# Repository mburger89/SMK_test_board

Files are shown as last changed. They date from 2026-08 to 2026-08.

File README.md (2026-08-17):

# SMK Test Board

A 3×3 macropad built around the Seeed XIAO ESP32-C6, with a rotary encoder and
per-key RGB. It exists to validate the [SMK](https://github.com/mburger89/SMK)
keyboard firmware and the
[SMK Configurator](https://github.com/mburger89/smk_configurator) editor on real
hardware — small enough to be cheap, complete enough to exercise every subsystem
the full keyboard depends on.

Two of those subsystems have never run against physical hardware at all: the RMT
LED driver and `BatteryMonitor`. This board is where they get their first test.

**The schematic and PCB are generated by a Python script, not drawn by hand.**
`generate_test_board.py` is the source of truth; the files under
`smk_test_board/` are its output and should never be hand-edited.

## Status

Design complete, reviewed, and DRC-clean. **Not yet fabricated.**

Before ordering, `docs/fabrication.md` opens with a STOP gate: two footprints —
`XIAO_ESP32C6_HEADERS` and `EC11_VERTICAL` — were drawn from datasheet
dimensions and have never been checked against real parts. Print the board 1:1
and hold the physical XIAO and EC11 against the paper first. A wrong
castellation pitch or encoder pin spacing is not reworkable; it means a second
fab run.

## What's on it

| | |
|---|---|
| MCU | Seeed XIAO ESP32-C6 on 1×7 female headers |
| Matrix | 3×3, 19.05 mm pitch, Gateron KS-33 hot-swap sockets, SOD-123 diodes |
| Encoder | EC11 vertical; its push-switch **is** matrix position row 0, col 2 |
| RGB | 9 × SK6812MINI-E, reverse-mount, one per key, behind an SN74AHCT1G125 level shifter |
| Power | USB-C on the XIAO, or a single-cell Li-ion via JST **SH** (1.0 mm) with flying leads to the module's underside BAT pads |
| Battery sense | External 1:2 divider (2 × 200 kΩ) into GPIO 0 |
| Board | 2-layer, 76.0 × 113.16 mm, 1.6 mm |

The nine LEDs are reverse-mount and shine *through* milled windows in the board
into each switch's north opening. Those windows are internal `Edge.Cuts`
cutouts, not decoration — a fab house that ignores them produces a board whose
LEDs do nothing.

## Pin map

This is a contract shared by four repositories, and all four must agree:

| Signal | GPIO |
|---|---|
| ROW0–2 | 1, 2, 21 |
| COL0–2 | 22, 23, 16 (`colsAreDriven = 1`) |
| LED data | 20 |
| VBAT sense | 0 (ADC1_CH0) |
| Encoder A/B | 17, 19 |

The four places it appears: `generate_test_board.py`'s `PIN` map, the firmware's
`Main.swift`/`Kconfig.projbuild`, the configurator's
`KeyboardDesign.smkTestBoard`, and this repo's `keymap.json`.

**Encoder rotation is not implemented.** GPIO 17/19 are wired and idle — nothing
decodes quadrature yet. That gets its own design once this board physically
exists. The encoder's *push* works, because it is an ordinary matrix position.

The LED chain is wired **serpentine** (even rows left-to-right, odd rows
right-to-left) to match `ledChainIndex()` in the firmware's
`SMKCore/LEDChainMapping.swift`. This is easy to get wrong and invisible when you
do: on a 3×3, raster and serpentine order agree on rows 0 and 2 and differ only
on row 1. `test_led_chain_order_matches_firmwares_serpentine_mapping` checks all
nine positions for exactly that reason.

## Layout

```
generate_test_board.py     the generator — schematic, PCB, placement, netlist
export_fab.py              gerbers, drill files, and the fab zip
test_test_board.py         netlist, placement, and cross-repo contract tests
test_footprints.py         footprint geometry tests
keymap.json                reference keymap (mo:1 on the encoder press)
smk_test_board/            generated KiCad project — do not hand-edit
smk_test_board.pretty/     local footprint library
docs/fabrication.md        BOM, order spec, DRC triage, pre-order gate
docs/bring-up.md           11-step procedure for a delivered board
docs/superpowers/          design spec and implementation plan
```

## Working on it

```bash
python3 -m venv venv && venv/bin/pip install pytest
venv/bin/python -m pytest          # 23 tests
python3 generate_test_board.py     # regenerate the KiCad project
python3 export_fab.py              # gerbers + drill + zip into gerbers/
```

Regeneration is byte-reproducible, UUIDs included — so after any change to the
generator, `git diff` on `smk_test_board/` shows exactly what moved
electrically. If you expected a documentation-only change and the `.kicad_pcb`
moved, that is a real finding, not noise.

Fabrication output lands in `gerbers/` and is gitignored. Generate it fresh at
order time rather than trusting a checked-in copy.

## Bringing one up

`docs/bring-up.md` is an ordered checklist with a blank result field per step.
The order matters: continuity checks happen **before** the XIAO is ever seated,
and the battery flying leads get soldered before anything is powered from a
cell.

Two things reliably waste an afternoon if you don't know them, and both are
called out in that document:

- The firmware's board selection defaults to the *other* board. Flash without
  changing it and you get the wrong pin map, and every matrix test fails
  confusingly.
- Two-Mac bonding needs `CONFIG_BT_NIMBLE_MAX_BONDS=4`. With the default of 1,
  the second Mac evicts the first and the test cannot pass.

## Known and accepted

- The board ships **ratsnest-only** — no copper routing. `unconnected_items` in
  DRC is expected and is not something to "fix."
- `min_copper_edge_clearance` is relaxed to 0.2 mm in the project file, because
  the SK6812 pads sit ~0.233–0.247 mm from their own light windows. That is a
  **relaxed rule, not a passing check.** The basis for proceeding is precedent:
  the sibling `smk_kbd_rp2040` board shipped 59 instances of this exact
  footprint at the same clearance.
- RGB3 will be visibly dimmer than the rest — the EC11's body covers roughly the
  southern half of its light window. Expected, not a fault.
- Li-ion cells are commonly sold with a JST-**PH** (2.0 mm) pigtail, which will
  not mate with this board's **SH** (1.0 mm) connector. Source an SH cell, an
  adapter, or re-terminate.

## Related

- [SMK](https://github.com/mburger89/SMK) — the firmware. Board config lives
  behind `CONFIG_SMK_BOARD_TEST_BOARD`.
- [SMK Configurator](https://github.com/mburger89/smk_configurator) — the
  keymap editor. `KeyboardDesign.smkTestBoard` describes this board's layout,
  and the DEV pane uploads `keymap.json` to it over BLE.

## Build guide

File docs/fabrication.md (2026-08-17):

# Fabrication — SMK Test Board (rev A)

Bring-up board for SMK's matrix, RMT LED driver, and `BatteryMonitor` on the
ESP32-C6 (Seeed XIAO ESP32-C6). 3x3 key matrix + EC11 rotary encoder, 9x
SK6812MINI-E per-key RGB. See
`docs/superpowers/specs/2026-08-16-smk-test-board-design.md` for the full
design.

## STOP — pre-order gate

**Do not order this board before printing `smk_test_board/smk_test_board.kicad_pcb`
at 1:1 scale and physically checking two footprints against real parts:**

- `XIAO_ESP32C6_HEADERS` — the Seeed XIAO ESP32-C6's 2x7 castellated/header
  footprint.
- `EC11_VERTICAL` — the rotary encoder's footprint.

Both were hand-drawn from datasheet dimensions in Tasks 3 and 4 of this
project and **have never been checked against a physical part.** No other
footprint in this design is new — the switch, diode, LED, passive, and JST
footprints all come from the proven `~/esp/SMK_macro_pad` sibling generator.
These two are the entire risk surface for "board arrives and a part doesn't
fit." A wrong castellation pitch or encoder pin spacing is not reworkable;
it means a second fab run. Print, hold the real XIAO and EC11 against the
paper, and only then run `export_fab.py` for real and place the order.

(`BAT_WIRE_PADS`, added later for the battery flying leads, is also new to
this project, but it is two 1.0 mm-drill through-hole pads on a 5.08 mm
pitch with nothing to mate against — there is no part to check it against
and no way for it to not fit. It does not join the gate.)

This check was **not performed** as part of this task — it requires a
printer and the physical parts, both outside an agent's reach. It is
recorded here as a hard gate for whoever places the order.

## Order specification

| | |
|---|---|
| Fab house | JLCPCB |
| Service | **Bare PCB only — no PCBA/assembly.** See reasoning below. |
| Layers | 2 |
| Dimensions | 76.0 x 113.16 mm |
| Thickness | 1.6 mm |
| Copper weight | 1 oz (JLCPCB default; board has no controlled-impedance or high-current nets that need more) |
| Surface finish | HASL (lead-free) |
| Soldermask / silkscreen | JLCPCB defaults (green / white) — cosmetic only, not specified by the design |
| Min hole / min trace-space | 21 plated holes (all 1.0 mm) and 30 unplated (2.4/3.0/3.2/5.2 mm — the largest is the Gateron hot-swap socket's own centre hole, one per socket). Matrix/LED/passive pads are standard sizes from the proven sibling footprint library. |
| Milled internal cutouts | **9 SK6812MINI-E light windows**, ~3.63 × 3.23 mm rounded rectangles (the real milled opening — the arcs' control-point bounding box, ~3.49 × 3.09 mm, understates it by ~0.15 mm per axis), one per LED, on `Edge.Cuts`. They are not optional decoration: these are reverse-mount LEDs on the back that shine *through* the board. Tightest copper-to-cut on the board is here — see the DRC triage below and checklist item 5. |

**Why bare boards, no PCBA:** at 9 switches, 9 LEDs, 9 diodes, one MCU
module, one encoder, and a handful of passives, JLCPCB's per-unique-part
assembly fee buys nothing at this part count, and the Gateron KS-33
hot-swap sockets and the through-hole EC11 aren't SMT-assembled parts
anyway. Hand assembly is the right call, matching the design spec's §8
call. Components split across both sides: switches, diodes, and the 9
LEDs mount on the **back**; the XIAO module, encoder, level shifter, and
passives mount on the **front** — both sides need populating regardless of
who solders them.

**The board ships ratsnest-only.** Like its `~/esp/SMK_macro_pad` siblings,
routing copper is a separate concern from this task; nothing on this board
has been routed, and JLCPCB doesn't need routed copper to fab bare boards —
only Gerbers/drill for the layers and holes that exist. Do not route this
board as part of ordering it.

## Bill of materials

From the design spec §8 (`docs/superpowers/specs/2026-08-16-smk-test-board-design.md`).

**On hand already:**

| Qty | Part |
|---|---|
| 1 | Seeed XIAO ESP32-C6 |
| 8 | Gateron low-profile (KS-33) switches |
| 1 | EC11 rotary encoder |
| 9 | 1N4148 diodes (one per matrix position, encoder push switch included) |

**To source:**

| Qty | Part | Notes |
|---|---|---|
| 9 | SK6812MINI-E | per-key RGB |
| 9 | Gateron KS-33 hot-swap sockets | |
| 1 | Level shifter, LED data line | **SN74AHCT1G125DBVR**, SOT-23-5 — same part `~/esp/SMK_Keyboard`'s RP2040 board uses (its U7), LCSC **C7484**. This board's schematic already carries it as U2. |
| 2 | 1x7 female headers | for the XIAO module |
| 1 | JST SH 2-pin connector, 1.0 mm pitch (SM02B-SRSS-TB or equivalent) | battery — **not JST-PH**, see note below |
| 12 | 100 nF capacitors | 9 for LED decoupling (one per RGB, C1–C9), 2 for encoder debounce (C10/C11), 1 for the level shifter U2's own VCC (C12) |
| 1 | 100 µF bulk capacitor | LED chain entry (C_BULK) |
| 2 | 200 kΩ resistors, 0603 | **R1/R2, the VBAT sense divider** — VSYS → R1 → midpoint → R2 → GND, midpoint on U1 pad 1 (D0 / GPIO0 / ADC1_CH0). Not optional: without them U1 pad 1 floats and firmware reads garbage as a battery voltage. 200 k (not 100 k/10 k) keeps the standing drain at ~10 µA on a 4.2 V cell. |
| — | 2 short lengths of insulated wire | **Battery flying leads.** Soldered from `J2` (the through-hole pad pair silkscreened `BAT+`/`BAT-` beside U1) to the XIAO module's **underside** BAT+/BAT− solder pads. `J2` itself needs no part — it is two plated holes — but the assembly step is mandatory and is the *only* path from the JST connector to the module. See `docs/bring-up.md` step 1b-ii. |
| 4 | **M2** standoffs/screws | mounting; the board's four corner holes are 2.4 mm NPTH (`MountingHole_M2`). This line said "M3" and the design spec's §5 said "4 × M3 at the corners"; both were wrong against the board and are corrected. |
| — | Low-profile keycaps | 9x, to fit Gateron KS-33 |

> **Battery connector pitch — read before ordering a cell.** The board's
> battery connector is **JST SH, 1.0 mm pitch**, not the more common
> JST-PH (2.0 mm). Single-cell Li-ion pouch cells are very commonly sold
> with a **JST-PH 2.0 mm** pigtail pre-attached — that pigtail will
> **physically not mate** with this board's SH connector; the two are
> different, incompatible parts, not a tolerance issue. Before ordering a
> cell, do one of: (a) source a cell with a JST-SH 1.0 mm pigtail, (b) buy
> a JST-PH-to-JST-SH adapter cable, or (c) buy a cell with flying leads (or
> a PH pigtail) and re-terminate it onto an SH connector yourself. Getting
> this wrong is a several-day reorder, not a rework.

**Not on this board:** the "2 × 10 kΩ resistors (encoder pull-ups)" this BOM
used to list, and the design spec §2 line calling them "footprinted but may
be left unpopulated". No such footprints were ever drawn. Both documents are
corrected rather than the parts added: the spec's own reasoning is that the
ESP32-C6's internal pull-ups suffice, firmware does not read the encoder's
A/B until phase 2, and two more footprints on a bring-up fixture is two more
things to get wrong for no benefit. If phase 2 finds the internal pull-ups
marginal, that is when to add them.

The sibling `~/esp/SMK_macro_pad/smk_macropad/JLCPCB_Sourcing_Report.md` is
the precedent for part selection on this ecosystem's boards and should be
consulted for the level shifter and passives rather than re-deriving fresh
LCSC part numbers — it's where the SN74AHCT1G125DBVR / C7484 pairing above
came from (matched against the RP2040 keyboard board's own U7, not
re-guessed).

## DRC state and triage

Run with:

```bash
kicad-cli pcb drc --output drc.rpt --severity-error \
  smk_test_board/smk_test_board.kicad_pcb        # errors only
kicad-cli pcb drc --output drc_full.rpt \
  smk_test_board/smk_test_board.kicad_pcb          # errors + warnings
```

Errors-only run: **16 violations, 94 unconnected items, 0 footprint
errors.** Full run (errors + warnings): **102 violations, 94 unconnected
items.** At zero and staying there: `hole_clearance`, `solder_mask_bridge`,
`npth_inside_courtyard`, `copper_edge_clearance`, `text_height`,
`lib_footprint_issues`.

### Change against the previous state

The previous table read 16 `courtyards_overlap`, 86 `unconnected_items`, 46
`lib_footprint_issues`, 37 `silk_over_copper`, 36 `silk_overlap` (135 total; the full run is now 102).
Every moved number is accounted for below; none of it is rounding.

| Category | Was | Now | Severity | Blocks fab? | What moved, and why |
|---|---|---|---|---|---|
| `courtyards_overlap` | 16 | **16** | error | **No** | Unchanged. Every instance is this board's own declared-expected same-key stack: a switch with its own diode and LED beneath it. Courtyard overlap is a placement-density signal, not an electrical or manufacturing defect — the diodes/LEDs sit on the opposite board side from the switch bodies. Expected by design on a deliberately dense 19.05 mm-pitch 3x3 macropad. The four parts added this round (J2, R1, R2, C12) were all placed by the obstacle-aware search against real courtyards and add none. |
| `unconnected_items` | 86 | **94** | error | **No** | +8, all from the new parts, and every one of them is ratsnest on a board that ships deliberately unrouted (see below). Exactly: GND 25→28 (J2 pad 2, R2 pad 2, C12 pad 2), VSYS 20→23 (J2 pad 1, R1 pad 1, C12 pad 1), and a new `VBAT_SENSE` net at 2 (three nodes — U1 pad 1, R1 pad 2, R2 pad 1 — is two ratsnest links). Nothing that was connected became unconnected. |
| `lib_footprint_issues` | 46 | **0** | warning | **No** | Gone, and the old explanation for them was wrong. This document used to blame "running `kicad-cli` outside the full KiCad project environment". `kicad-cli` reads the project directory perfectly well; there was simply no `fp-lib-table` committed, so neither `smk_test_board:` nor `kbd:` resolved. Fixing it took three things: (1) the generator now writes `smk_test_board/fp-lib-table` and the `.kicad_pro` the design spec §5 always promised; (2) `kbd:` pointed at a `kbd.pretty` inside a *sibling repo*, so the six `generate_macropad.py` footprints this board uses are now re-emitted into the project's own `smk_test_board/kbd.pretty` and the board is self-contained; (3) `EC11_VERTICAL.kicad_mod` and `XIAO_ESP32C6_HEADERS.kicad_mod` contained `;;` comment lines — KiCad's s-expression parser has no comment syntax, rejects the file, and then refuses to load the **entire** library. That last one is why registering the library alone did not help, and it had been sitting in two committed files unnoticed; the rationale those comments carried now lives in each footprint's `(descr ...)`, which KiCad actually reads. |
| `lib_footprint_mismatch` | 0 | **9** | warning | **No** | New — and new only because the libraries now resolve at all; this check could not run before. All nine are C1–C9, the per-LED decoupling caps, the only parts on this board placed **back-side** via `gm.fp_0603(side="B")`. Cause: KiCad flips a footprint to the back by mirroring about the **X** axis (y → −y), while `generate_macropad.py`'s `_sx()` mirrors about the **Y** axis (x → −x). The two differ by a 180° rotation, so KiCad's comparison sees a mismatch. For an 0603 the copper, mask, paste, silk and fab geometry are all symmetric and **identical** either way — only which pad is numbered 1 changes, and C1–C9 are non-polar 100 nF ceramics, so nothing on this board is affected. It would matter for a *polarised* or pin-asymmetric part placed back-side through the same helper; `test_back_side_passives_are_all_nonpolar` guards that. Not fixed here because `generate_macropad.py` is a shared module four other generated boards depend on. |
| `silk_over_copper` | 37 | **38** | warning | **No** | +1 net: −2 (C10 moved off ENC1's reference field, see the `copper_edge_clearance` note) and +3 new (R1's designator over R2's two pads; U2's designator over C12's GND pad). Same root cause as the existing 35: reference-designator text on a dense board clipping a neighbour's soldermask opening. Cosmetic on a fixture assembled by the person who designed it. |
| `silk_overlap` | 36 | **38** | warning | **No** | +2 net: −2 (ENC1 ref vs C10's silk; ENC1's silk rect vs C11's ref — both cleared when C10/C11 moved) and +4 new (C10 and C11 designators against ENC1's silk envelope at their new position, U2's designator against C12's silk, R1's designator against R2's silk). Silk-on-silk crowding; no copper, mask or paste consequence. |
| `silk_edge_clearance` | 0 | **1** | warning | **No** | New, and a direct consequence of milling the LED light windows: at row 0 / col 2 the EC11 shares its matrix cell with RGB3, so ENC1's silkscreen envelope now crosses RGB3's window. Two instances were introduced; one was fixed by moving ENC1's reference designator from y=−8 to y=−9 in the footprint (text placement only — no pad, hole or courtyard change, so the 1:1 print gate is unaffected). The remaining one is ENC1's silk *rectangle* edge, which cannot move without shrinking the envelope below the encoder's real body-plus-posts extent. Silk printed over a milled opening simply isn't printed; nothing electrical. |
| `copper_edge_clearance` | 0 | **0** | error | **No** | Zero, but it did not start that way and the story matters. Adding the Edge.Cuts windows put 38 copper-to-edge violations on the board. **Two of them were a real defect**: C10, the encoder's debounce cap, had a pad sitting at 0.00 mm from RGB3's window — copper the router would have cut in half. The generator's cap-placement search knew about the EC11's pins and body but not about the LED, and the generator's own overlap scan could not see it either, because C10 and RGB3 share matrix position (0,2) and same-position overlaps are declared expected. Fixed by adding the LED's courtyard to that search. The other 36 are each SK6812MINI-E pad against **its own** light window at 0.2467 mm, which is what the stock KiCad `LED_SK6812MINI-E_3.2x2.8mm_P1.5mm_ReverseMount` footprint measures, used unmodified — the same footprint the sibling `~/esp/SMK_Keyboard/smk_kbd_rp2040` board carries **59** instances of, at this same clearance, and has fabricated successfully. The project's `.kicad_pro` sets `min_copper_edge_clearance = 0.2 mm`, below the real clearance, specifically so this reads as zero errors — that is a **relaxed rule, not a passing check**; it silences the report, it does not mean the clearance is generous. **See the ordering checklist for the number and the precedent an operator actually confirms before proceeding.** |
| `text_height` | 0 | **0** | warning | **N/A** | Appeared briefly (2) when J2's `BAT+`/`BAT-` silk was drawn at 0.8 mm, below the project's own silk-text floor; the labels are 1.0 mm and it is back to zero. |

**Why `unconnected_items` is not a blocker.** This board ships ratsnest-only,
exactly like its `~/esp/SMK_macro_pad` siblings. Routing copper is out of
scope for this fab order; JLCPCB fabs whatever copper/drill data is in the
Gerbers, and there is none pending beyond what's placed.

**On the copper-to-edge number.** This document used to claim KiCad measures
to the *outer edge* of the 0.12 mm-wide `Edge.Cuts` graphic, and that the gap
to the **nominal cut path** the router actually follows is **0.3067 mm** —
"the number to compare against a fab's published copper-to-slot capability."
That is false, and was disproved directly: widening every Edge.Cuts stroke on
the window from 0.12/0.15 mm to 0.4 mm changed the reported DRC clearances
**not at all** (still 3 × 0.2467, 1 × 0.2468, 3 × 0.3154, 29 × 0.3500 mm).
KiCad's copper-to-edge check ignores `Edge.Cuts` stroke width entirely —
**0.2467 mm, as KiCad reports it, is already the copper-to-centreline
number**, not a figure that needs a stroke-width correction added on top.
Reconstructing the corner arcs exactly (r = 0.5 mm, centres at footprint-local
±(1.3171, 1.1171) mm) puts the true minimum tighter still, at **≈0.2329 mm**:
pad 1's edge at local x = −2.05 mm against the arc's leftmost point at
x = −1.8171 mm.

The basis for proceeding is not "0.2467 mm (or 0.2329 mm exact) happens to
clear some fab's published number" — a fab spec is worth checking but isn't
what justifies this board. The basis is precedent: the sibling board
`~/esp/SMK_Keyboard/smk_kbd_rp2040` carries **59** instances of this exact
SK6812MINI-E footprint at this same 0.2467 mm clearance and was fabricated
successfully. That is what licenses fabricating this one too.

The project's `.kicad_pro` sets `min_copper_edge_clearance = 0.2 mm`, below
both numbers above, specifically so DRC reports zero `copper_edge_clearance`
errors here. That is a **relaxed rule, not a passing check**: it turns down
the check that would otherwise flag this clearance, it does not mean the
clearance is comfortable. A green DRC run must not be read as "no tight
clearance exists." None of this can be improved without redrawing the
SK6812MINI-E footprint, which would mean redrawing the light window it exists
for.

**Known cosmetic limitation, row 0 / col 2.** The EC11's 12 × 12 mm body sits
over roughly the southern half of RGB3's light window (the window spans
y = −7.57…−4.48 mm from the key centre; the encoder body reaches y = −6.0 mm).
No pin or mounting post falls inside the opening, so there is no mechanical or
electrical problem, but RGB3 will be visibly dimmer than the other eight. That
is inherent to putting a per-key LED under a rotary encoder at the same matrix
position — both positions are frozen cross-repo contracts.

**Earlier silk work, retained:** the board's single title text
(`"SMK TEST BOARD -- 3x3, XIAO ESP32-C6 + EC11 rev A"`, placed in
`generate_test_board.py`'s PCB writer, not a footprint) originally sat at
`(5, 4)` — inside mounting hole H1's silkscreen circle and clipped by the top
board edge. Moving it to `(7, 10.5)` and shrinking it from 2 mm to 1.2 mm
cleared a `silk_edge_clearance` violation and two entries each from the silk
categories. Still in place.

**What is deliberately left:** the ~76 `silk_over_copper` / `silk_overlap`
warnings tied to per-key stacking density, the single `silk_edge_clearance`
instance at the encoder, and the nine `lib_footprint_mismatch` warnings.
Chasing the silk crowding further would mean loosening the deliberately tight
19.05 mm key pitch or hand-tuning per-footprint text offsets; the mismatch
warnings are a shared-helper convention difference with no geometric
consequence for the non-polar parts involved (see the table).

## Gerber export

```bash
python3 export_fab.py
```

Drives `kicad-cli pcb export gerbers` and `kicad-cli pcb export drill`
(structure follows `~/esp/SMK_Keyboard/smk_kbd_rp2040/export_fab.py`, minus
its zone-fill step — this board has no copper zones/pours to fill, and the
script asserts that and fails loudly if a future revision adds one without
updating it). Output lands in `gerbers/` (gitignored) plus a zipped copy at
the repo root, `smk_test_board_gerbers.zip` (also gitignored, `*.zip`) —
upload that zip to JLCPCB.

Resulting file set (15 files):

```
gerbers/
  smk_test_board-F_Cu.gtl            smk_test_board-B_Cu.gbl
  smk_test_board-F_Mask.gts          smk_test_board-B_Mask.gbs
  smk_test_board-F_Silkscreen.gto    smk_test_board-B_Silkscreen.gbo
  smk_test_board-F_Paste.gtp         smk_test_board-B_Paste.gbp
  smk_test_board-Edge_Cuts.gm1
  smk_test_board-job.gbrjob
  smk_test_board-PTH.drl             smk_test_board-NPTH.drl
  smk_test_board-PTH-drl_map.gbr     smk_test_board-NPTH-drl_map.gbr
  drill-report.txt
```

## Ordering checklist

1. **1:1 print check against real XIAO ESP32-C6 and EC11 parts — see the
   gate at the top of this document. Do not skip.**
2. `./venv/bin/python generate_test_board.py` — regenerating an unchanged
   generator must produce a **byte-identical** `.kicad_pcb`/`.kicad_sch`
   (`git status` clean). If it doesn't, something is non-deterministic and
   "did the board actually change?" stops being answerable.
3. `./venv/bin/python -m pytest -q` — **23/23** should pass. (It was
   12 tests when this document first claimed "12/12", 13 by the time the
   claim was last edited, and 23 now.)
4. `kicad-cli pcb drc --severity-error` — should show **16 violations / 94
   unconnected**, all triaged above as non-blocking. Any *new* error
   category is a real regression; stop and investigate before ordering.
5. **Confirm the tightest clearance on the board against precedent, not
   against "it happens to clear a fab spec."** The nine SK6812MINI-E light
   windows sit **0.2467 mm** from their own LED pads as KiCad measures it
   (**≈0.2329 mm** exact, reconstructing the corner arcs — KiCad's own
   figure is already the copper-to-centreline number; there is no separate
   "nominal cut path" figure to add on top, despite what an earlier
   revision of this document claimed). This is the single tightest
   clearance on the board, and the project's `.kicad_pro` relaxes
   `min_copper_edge_clearance` to 0.2 mm specifically so DRC doesn't flag
   it — that is a relaxed rule, not evidence the clearance is comfortable.
   What actually justifies proceeding: the sibling
   `~/esp/SMK_Keyboard/smk_kbd_rp2040` board carries **59** instances of
   this exact stock reverse-mount footprint at this same 0.2467 mm
   clearance and has been fabricated successfully. Confirm that precedent
   still holds (nothing about this footprint changed since) and, as a
   secondary check, that it's also within the fab's *current* published
   copper-to-slot capability.
6. **Confirm `gerbers/smk_test_board-Edge_Cuts.gm1` contains the nine LED
   windows**, not just the board outline: `grep -cE '^G0[23]\*$'
   gerbers/smk_test_board-Edge_Cuts.gm1` must be **108** (9 LEDs × 12 arcs
   per window). These are reverse-mount LEDs shining *through* the board;
   with no windows they do nothing, and it is not reworkable after fab.
   This is the exact defect that reached this checklist once already — an
   earlier revision of this step gave a command that grepped
   `smk_test_board.kicad_pcb` (the source file) rather than the gerber
   actually being confirmed, so it could pass without checking what the
   step claims to check.
7. `python3 export_fab.py` — regenerates `gerbers/` and the zip fresh from
   the current board file. Cross-check `gerbers/drill-report.txt`: **21
   plated / 30 unplated** holes.
8. Upload `smk_test_board_gerbers.zip` to JLCPCB. Select: 2 layers, 1.6 mm,
   HASL, no PCBA/assembly service.
9. Source the BOM above (`JLCPCB_Sourcing_Report.md` precedent for the
   level shifter and passives) and hand-solder/hand-place on arrival.
   **Do not skip the two battery flying leads** (`J2` → the XIAO's
   underside BAT+/BAT− pads): they are the board's only path from the JST
   cell connector to the module. See `docs/bring-up.md` step 1b-ii.

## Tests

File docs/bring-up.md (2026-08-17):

# Bring-up — SMK Test Board (rev A)

Procedure for turning a freshly fabricated/assembled board into a validated
one. Transcribed from the design spec's §9 acceptance checks
(`docs/superpowers/specs/2026-08-16-smk-test-board-design.md`) into an
ordered, checkable form.

**Do these in order.** Power and continuity come before the XIAO module is
ever seated, and matrix/layer checks come before anything wireless — each
step assumes every step above it already passed. If a step fails, stop and
fix it before continuing; a later step's result is not trustworthy if an
earlier one didn't actually pass.

Board reference: `docs/superpowers/specs/2026-08-16-smk-test-board-design.md`.
Fabrication reference: `docs/fabrication.md`. Firmware: `~/esp/SMK`
branch `test-board-config` (commit 171f67c). Configurator: `~/esp/smk_configurator`
branch `test-board-design` (commit dfd84da). Reference keymap: `keymap.json`
in this repo.

Every checkbox below has a blank **Result** line. This document was written
without hardware in hand — nothing in it has been run. Fill in each result
as you go; don't check a box you haven't actually observed.

---

## Before you start: the footprint gate

Two footprints on this board — `XIAO_ESP32C6_HEADERS` and `EC11_VERTICAL` —
were hand-drawn from datasheet dimensions and had never been checked against
physical parts as of fabrication (`docs/fabrication.md`'s "STOP — pre-order
gate"). If that 1:1 print check happened before this board was ordered, its
result belongs there, not here. If it didn't, or you're not sure, **Step 1
below is your first chance to catch a footprint error** — a header row that
doesn't seat, or encoder pins that don't line up with the PCB's holes both
show up as soon as you hold the real parts against the board.

---

## Step 1 — Visual inspection and continuity

Before the XIAO is seated. Power checks come first because a short here can
damage the XIAO the moment it's powered, and there is no way to undo that.

- [ ] **1a. Visual inspection.** No solder bridges, no lifted pads, no
  obviously cold joints. Check `XIAO_ESP32C6_HEADERS` and `EC11_VERTICAL`
  specifically — headers seat flush and square, encoder pins line up with
  their holes and the mounting posts aren't binding against the footprint's
  silkscreen/pads. (See "Before you start" above — this is where a
  never-checked footprint shows up.)

  Result: ______________________________________________

- [ ] **1b. VSYS–GND continuity.** Multimeter in continuity/low-resistance
  mode, board unpowered, XIAO **not yet seated**. Probe VSYS to GND at
  `J1` (the JST SH battery connector) or at **`J2`, the two through-hole
  pads silkscreened `BAT+` / `BAT-` beside `U1`** — `J2` pin 1 (`BAT+`,
  the square pad) is VSYS, pin 2 (`BAT-`) is GND. Do not look for a VSYS
  pad on the XIAO footprint: there isn't one and there can't be, because
  the module's battery terminals are on its underside (see Step 1b-ii).
  Expect **no continuity** (open, or a normal high-impedance reading — not
  a dead short).

  Note the reading will not be a true open: `R1`/`R2`, the VBAT sense
  divider, sit across VSYS→GND, so expect roughly **400 kΩ**. A dead short
  or a few ohms is the failure this step is looking for.

  Result: ______________________________________________

- [ ] **1b-ii. Solder the two battery flying leads.** With the XIAO
  **out** of its headers, solder two short insulated wires to `J2`:
  `BAT+` (square pad) and `BAT-`. Leave them long enough to reach the
  module's underside pads with it seated, and **do not connect a cell
  yet.**

  Then seat the XIAO and solder the free ends to its **underside**
  `BAT+` / `BAT-` solder pads. Getting these two backwards puts a Li-ion
  cell into the XIAO reversed — check the silk twice: the square pad and
  the drawn `+` are `BAT+` / VSYS; the round pad and the drawn `-` are
  `BAT-` / GND.

  This is the only path from the JST connector to the module. Without it
  the board runs on USB only, the onboard charger never sees the cell, and
  the LED chain and level shifter are unpowered whenever no cell is
  fitted.

  Result: ______________________________________________

- [ ] **1c. 3V3–GND continuity.** Same method as 1b. Probe the XIAO
  footprint's **3V3 pad (`U1` pin 12)** against a GND pad (`U1` pin 13, or
  any other GND point, e.g. `J1` pin 2). Note this rail isn't carried
  anywhere else on this board — `build_nets()` deliberately leaves U1 pin
  12 unwired, since nothing here consumes regulated 3.3V (the LEDs run
  from VSYS, and the level shifter is single-rail) — so this check is
  really validating there's no solder bridge on the XIAO header footprint
  itself between that pin and its GND neighbor, not a populated PCB net.
  Expect **no continuity**.

  Result: ______________________________________________

  If either 1b or 1c shows a dead short: stop. Do not seat the XIAO or
  apply power. Re-inspect for a solder bridge on the power rails before
  going any further.

---

## Step 2 — Seat the XIAO and power up

- [ ] **2a. Seat the XIAO ESP32-C6** module into its headers.

  Result: ______________________________________________

- [ ] **2b. Power over USB-C and confirm enumeration.** This board's
  firmware build has no USB HID path on ESP32-C6 (BLE + wired-UART only,
  per `~/esp/SMK/CLAUDE.md`'s target table — this board has no CH9350
  bridge either) — what you're confirming here is the XIAO's native
  USB-Serial/JTAG showing up as a new serial device, e.g.
  `ls /dev/tty.usbmodem*` (macOS), so `idf.py flash` has something to talk
  to. A device that doesn't enumerate at all points at the XIAO seating, a
  bad USB-C cable/port, or a dead module — not yet a board wiring problem.

  Result: ______________________________________________

---

## Step 3 — Flash the test board build

- [ ] **3a. Select the board variant in Kconfig before building.**
  `~/esp/SMK`'s `main/Kconfig.projbuild` defines a `choice SMK_BOARD` whose
  **default is `SMK_BOARD_SMK_KBD`** — the *other* board, the 5×12
  reference keyboard, not this one. If you skip this, the firmware
  compiles and flashes cleanly and every matrix test below fails
  confusingly, because it's scanning a pin map for a keyboard this board
  isn't.

  ```bash
  . ~/.espressif/v6.0.1/esp-idf/export.sh
  cd ~/esp/SMK
  idf.py set-target esp32c6    # one-time, if not already set
  idf.py menuconfig
  ```

  In the menu: **SMK Keyboard Configuration → Board variant**, select
  **"SMK test board (Seeed XIAO ESP32-C6, 3x3 macropad bring-up board)"**
  (`CONFIG_SMK_BOARD_TEST_BOARD`). Save and exit.

  Result: ______________________________________________

- [ ] **3b. Check whether this build actually supports two bonded hosts —
  Step 11 depends on it, and it is not this branch's job to fix.**
  `test-board-config`'s `sdkconfig.defaults` carries
  `CONFIG_BT_NIMBLE_MAX_BONDS=1`. The `=4` that Step 11 (two-Mac bonding)
  needs lives on the separate, unmerged `ble-custom-gatt` branch
  (`git show ble-custom-gatt:sdkconfig.defaults`) — this is not a defect on
  `test-board-config` to patch here, it resolves whenever that branch
  merges (or you build from it directly). **Do not set this via
  `idf.py menuconfig`** — that write lands only in the gitignored,
  machine-local `sdkconfig` and silently reverts on the next clean
  checkout, which is exactly how someone ends up chasing a "bonding
  failure" that isn't a hardware problem at all.

  Instead, check what you actually built, after `idf.py build` has
  generated a real `sdkconfig`:

  ```bash
  grep CONFIG_BT_NIMBLE_MAX_BONDS ~/esp/SMK/sdkconfig
  ```

  If it reads `=1`, Step 11 is expected to fail — pairing a second Mac
  will evict the first from the (single-slot) bond store rather than both
  coexisting, which is a build-configuration gap, not a board defect. Note
  which branch/commit you actually built from here so Step 11's result is
  interpretable.

  Result: ______________________________________________

- [ ] **3c. Build and flash.**

  ```bash
  idf.py build
  idf.py flash monitor
  ```

  Confirm the flash completes without error and the monitor shows the
  firmware booting (no boot-loop, no crash backtrace).

  Result: ______________________________________________

---

## Step 4 — Matrix

The compiled-in default keymap for this board (`Sources/smk/Main.swift`,
`#elseif SMK_BOARD_TEST_BOARD` branch) is a single flat layer,
`key:1`…`key:9`, one keycode per matrix position, row-major — nothing
uploaded yet. Use it as-is for this step; don't load anything in the
configurator until Step 5.

- [ ] **4a. All 9 positions register.** Press each of the 9 physical
  positions in turn (the 8 Gateron switches plus the encoder's integrated
  push-switch) and confirm each one reports a distinct keystroke 1–9 with
  nothing missing and nothing duplicated. **The encoder's contribution here
  is its push-switch only — press straight down on the knob.** Nothing in
  this firmware build decodes rotation (GPIO17/GPIO19 are wired but
  unread — quadrature decoding is a later spec, out of scope for this
  board's bring-up); turning the knob left or right is expected to do
  **nothing**, and that is not a failure.

  Physically, the encoder's push-switch is wired at matrix **row 0 / col
  2** — confirmed independently in three places: `generate_test_board.py`'s
  `build_nets()` (`ENC1` pad 4 → `COL2`, pad 5 → the diode side of
  `D02`, whose cathode is on `ROW0`), the design spec's §1/§2, and
  `Main.swift`'s own comment on this board's default keymap ("row 0, col 2
  is the rotary encoder's push switch"). If you're cross-referencing
  against the schematic, that's the position to press for "encoder"; the
  other 8 are ordinary Gateron switches.

  Result (list each of the 9 positions and what it typed):
  ______________________________________________
  ______________________________________________

- [ ] **4b. No ghosting on a three-key L.** Hold down three keys forming an
  L-shape in the 3×3 grid (e.g. two keys in one row plus one key in a
  different row, sharing a column with one of the first two) and confirm
  exactly those three keystrokes register — no phantom fourth key from the
  diode matrix.

  Result: ______________________________________________

---

## Step 5 — Layers (`mo:` and `tg:`)

The compiled-in default keymap from Step 4 has no layers at all — one flat
9-key layer, no `mo:`/`tg:` tokens anywhere — so this step can't be
exercised without uploading a keymap that has them first. That upload is
what the rest of this step walks through.

`keymap.json` puts `mo:1` on the encoder's push-switch itself — grid
position **row 0 / col 2**, the same position Step 4a confirmed is the
encoder — so holding the encoder press is expected to change layers, and
the other 8 (ordinary Gateron) keys should show layer 1's values while it's
held. Layer 1 mirrors layer 0's grid with `f1`–`f8` in place of `1`–`8`,
and keeps `trans` at row 0 / col 2 so the encoder key falls through to its
own `mo:1` rather than shadowing it. **Rotation still does nothing** —
nothing in this firmware build reads GPIO17/GPIO19 (see Step 4a) — so
turning the knob while testing this is not a failure, only pressing it is
relevant here.

`keymap.json` has no `tg:` binding at all (design spec §9 check 2 wants
both `mo:` and `tg:` verified). Add one as part of the same upload, on an
ordinary key well away from the encoder — and on **both** layers, the same
way `mo:1`/`trans` are paired at row 0 / col 2: a `tg:` binding with no
matching `trans` underneath it on the layer it switches to has no way
back. `LayerEngine.getAction` only falls through to a lower layer when a
cell is literally `trans` — once layer 1 is active, pressing that same key
again resolves to whatever layer 1's own cell says, not layer 0's `tg:1`,
so if layer 1's cell is still an ordinary keycode, the second press just
types that keycode and the board is stuck on layer 1 with no way back
except a fresh upload.

- [ ] **5a. Load and edit the reference keymap.** In the configurator, File
  → Open `~/esp/SMK_test_board/keymap.json`. Its matrix (`rows: [1,2,21]`,
  `cols: [22,23,16]`, `colsAreDriven: 1`) matches `KeyboardDesign
  .smkTestBoard` exactly, so the app should auto-select that design — the
  key grid should render as a labeled 3×3, not a generic/unlabeled
  fallback. Remap **both** of these:
  - **row 2 / col 2, layer 0** (currently `key:8`) → `tg:1`.
  - **row 2 / col 2, layer 1** (currently `key:f8`) → `trans`.

  Leave everything else as-is, including the row 0 / col 2 `mo:1`/`trans`
  pairing on the encoder.

  Result: ______________________________________________

- [ ] **5b. Upload this edited keymap** via the DEV pane (see Step 7 below
  for what "upload" looks like mechanically over BLE — do that now, using
  this edited keymap as the payload, ahead of Step 7's own upload).

  Result: ______________________________________________

- [ ] **5c. `mo:` while held.** Hold the encoder's push-switch down (row 0
  / col 2 — press straight down on the knob, don't turn it). Confirm the
  other 8 keys emit `F1`–`F8` (per `keymap.json`'s layer 1) while it's
  held, and revert to their layer-0 values the instant you release it —
  no lag, no stuck layer.

  Result: ______________________________________________

- [ ] **5d. `tg:` latching.** Press and release the row 2 / col 2 key once
  (the `tg:1` you just added). Confirm the board **stays** on layer 1 —
  the other keys now emit `F1`–`F8` without anything held down. Press the
  same key again — because layer 1's row 2 / col 2 is now `trans` (Step
  5a), this falls through to layer 0's `tg:1` and toggles back — confirm
  it does. If it instead types `F8` and layer 1 stays active, Step 5a's
  layer-1 edit didn't take; re-check both cells before treating this as a
  device fault.

  Result: ______________________________________________

---

## Step 6 — BLE HID typing into a Mac

- [ ] **6a. Pair.** On a Mac, open Bluetooth settings and pair to
  **"SMK Keyboard"** — the device name is hardcoded
  (`Sources/components/ble_helper.c`) and is the same on every SMK board
  variant, so if there's another SMK board nearby, confirm you're pairing
  to this one (e.g. by its MAC/proximity, or by temporarily powering the
  other one off).

  Result: ______________________________________________

- [ ] **6b. Type.** Open a text field and press keys on the board (layer 0
  is fine — `1`–`8` plus the `tg:1` you added). Confirm each keystroke
  appears correctly and promptly.

  Result: ______________________________________________

---

## Step 7 — Keymap upload from the configurator, confirm a remap

This step specifically exercises the upload-and-confirm round trip called
out in the design spec's §9 check 4 ("the check the 2026-08-15 BLE work
could not perform, having no switches") — a fresh, isolated remap, separate
from Step 5's layer edits, so a failure here points at the upload path and
not at anything layer-related.

Note on what "connected" looks like: the configurator's BLE transport
(`Sources/SMKConfigurator/Device/BLETransport.swift`) has no live
connect-status indicator yet — the DEV pane's transport list always shows
BLE as "Not connected" even mid-upload (see that view's own comment). The
real signal is the upload itself: no error banner
("Couldn't send keymap to device: …") and `Send to Device` returning to its
idle label with a fresh "Last sent Xs ago" timestamp.

- [ ] **7a. Remap one key.** In the configurator (same session as Step 5,
  or reopen `keymap.json`), change the **row 0 / col 0** key (currently
  `key:1`) to `key:z`.

  Result: ______________________________________________

- [ ] **7b. Upload.** DEV pane → **Send to Device**. It tries USB first,
  finds nothing (this board has no USB HID path), then falls back to BLE
  automatically — no manual transport selection needed. Confirm no error
  banner appears and `Last sent` updates.

  Result: ______________________________________________

- [ ] **7c. Confirm the remap.** Press the row 0 / col 0 key and confirm it
  now types `z`, not `1`.

  Result: ______________________________________________

---

## Step 8 — Persistence across power cycle

- [ ] **8a. Power cycle the board** (unplug/replug USB, or full power-off
  if running on battery — see Step 10).

  Result: ______________________________________________

- [ ] **8b. Confirm the remap survived.** Press row 0 / col 0 again;
  confirm it still types `z`. If it reverted to `1`, the upload didn't
  actually persist to NVS — treat this as a firmware/storage bug, not a
  configurator bug (Step 7 already confirmed the upload path itself
  worked).

  Result: ______________________________________________

---

## Step 9 — RGB (first hardware validation of the RMT driver)

Nothing has exercised `LedStripDriverRMT.swift` against a real LED chain
before this board. Give this more than a pass/fail checkbox — a partial
failure here is the expected way a driver meets real hardware for the
first time, and where it fails tells you what's wrong.

This firmware's RGB isn't an idle animation — it's **per-key, reactive**:
`Main.swift` lights a key's LED solid white (255,255,255) on press and
turns it off on release (see `rgb?.setKey(...)` in the scan loop). "Lights
and animates" in the design spec's §9 means this — press a key, its LED
lights; release it, the LED goes dark. There is no boot-time rainbow or
idle pattern to wait for.

**Expected: RGB3 (row 0 / col 2, under the encoder) will look dimmer than
the other eight.** The EC11's 12 × 12 mm body covers roughly the southern
half of RGB3's light window (~49% of it) — reviewed and accepted at design
time, not a defect. Do not log this as a fault; log it only if RGB3 doesn't
light at all, or is dim enough to suggest something else is wrong (see
`docs/fabrication.md`'s DRC triage for the underlying geometry).

- [ ] **9a. Press each of the 9 keys in turn and watch its LED.** Expect:
  LED lights solid white while held, goes dark on release, and it's the
  **correct** LED under the key you pressed (the chain is wired
  serpentine — even rows run col 0→2, odd rows run col 2→0 — so a
  transposed row is a plausible failure mode, not just "some LED lights").

  Result (note any key whose LED doesn't match, is dim, wrong color, or
  doesn't light at all):
  ______________________________________________
  ______________________________________________

- [ ] **9b. If nothing lights at all:** `led_strip_driver_init` fails
  silently (no log line) if `rmt_new_tx_channel`/`rmt_new_led_strip_encoder`
  /`rmt_enable` return nonzero — check GPIO20 wiring, the SN74AHCT1G125
  level shifter's power (VCC from VSYS, not 3V3 — an unpowered shifter
  drives nothing downstream) and OE# (tied permanently to GND to enable
  it), and the 100µF bulk cap at the chain entry.

  Result: ______________________________________________

- [ ] **9c. If only the first LED (under whichever key you press) responds
  and the rest never do:** points at the chain wiring past RGB1 — a broken
  DOUT→DIN hop, a cold solder joint on one of the 9 SK6812MINI-E parts, or
  a reversed LED (DIN/DOUT swapped) partway down the chain. Isolate by
  checking continuity DOUT(n)→DIN(n+1) starting from RGB1.

  Result: ______________________________________________

- [ ] **9d. If colors look wrong (e.g. a key you expect white shows red or
  green):** the driver's wire format is GRB, MSB-first — a channel-order
  mismatch this early usually means a miswired LED footprint, not a
  software bug (this project's SK6812MINI-E footprint is the fab-proven
  one shared with `~/esp/SMK_Keyboard`, so a wiring/solder defect is more
  likely than a footprint error here).

  Result: ______________________________________________

---

## Step 10 — Battery (first hardware validation of `BatteryMonitor`)

Nothing has exercised `BatteryMonitor.swift`/`battery_adc.c` against a real
cell and a real divider before this board. As with Step 9, a plausible
partial failure needs somewhere to point, not just a checkbox.

`BatteryMonitor` reads GPIO0 (ADC1_CH0), doubles it (the board's VBAT÷2
divider — `R1`/`R2`, two 200 kΩ 0603s beside `U1`, VSYS → R1 → midpoint →
R2 → GND with the midpoint on `U1` pad 1; `vbatDividerRatio = 2` in
`BatteryMonitor.swift` is correct for it), then maps
3300mV–4200mV linearly to 0–100% and clamps outside that range. This is a
rough single-cell Li-ion approximation, not a calibrated discharge curve —
don't expect a precise number, but a **stable, plausible, slowly-falling**
one.

- [ ] **10a. Connect a charged single-cell Li-ion to the JST SH connector,
  unplug USB, and run untethered.** Confirm the board still functions
  (matrix/BLE) on battery alone.

  Result: ______________________________________________

- [ ] **10b. Check the reported percentage.** On the paired Mac, Bluetooth
  settings shows a battery percentage for "SMK Keyboard" (via the BLE HID
  Battery Service). Expect a plausible number (not 0%, not obviously
  wrong for a charged cell) that **falls slowly** over time/use, not one
  that's frozen or jumps erratically.

  Result: ______________________________________________

- [ ] **10c. If it's stuck at 0%:** the ADC reading is at or below
  3300mV/2 at the pin — check the VBAT divider's wiring and that the cell
  is actually connected/charged, before suspecting the ADC/firmware.
  Concretely: measure `U1` pad 1 against GND with a charged cell fitted.
  It should read about half the cell voltage (~1.9–2.1 V). Near 0 V means
  `R1` is open or unpopulated; near full cell voltage means `R2` is.

  Result: ______________________________________________

- [ ] **10d. If it's stuck at 100%, or implausibly high right after
  connecting a partially-discharged cell:** the pin reading is at or above
  4200mV/2 — check for the divider ratio being wrong (e.g. the pin
  actually seeing near-undivided VBAT, doubling an already-high reading)
  or the ADC pin shorted toward VSYS/3V3 rather than reading the true
  divider midpoint.

  Result: ______________________________________________

- [ ] **10e. If `smk_battery_adc_init` failed outright:** the serial
  monitor logs "Battery ADC init failed; battery reporting disabled"
  (`BatteryMonitor.swift`'s `initBatteryMonitor()`) — unlike Step 9's RMT
  driver, this failure path *does* log, so check `idf.py monitor` output
  first.

  Result: ______________________________________________

---

## Step 11 — Two-Mac bonding

Depends on Step 3b's check (`CONFIG_BT_NIMBLE_MAX_BONDS` in the build you
actually flashed). If that came back `=1` (the `test-board-config` default,
pending the unmerged `ble-custom-gatt` branch), **this step is expected to
fail** — pairing a second Mac evicts the first rather than both coexisting.
That is a build-configuration gap this branch inherits, not a result to
record against this board's hardware. Only treat a failure here as a real
finding if Step 3b's check came back `=4`.

- [ ] **11a. Pair to a first Mac**, confirm typing works (as in Step 6).

  Result: ______________________________________________

- [ ] **11b. Pair to a second Mac** (same device name, "SMK Keyboard" —
  see Step 6a's note), confirm typing works there too.

  Result: ______________________________________________

- [ ] **11c. Switch back to the first Mac** (put it in range / wake
  Bluetooth there) and confirm it **reconnects without re-pairing** —
  no "forgotten device" prompt, no re-entering a passkey.

  Result: ______________________________________________

- [ ] **11d. Switch to the second Mac** and confirm the same — reconnects
  without re-pairing.

  Result: ______________________________________________

---
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

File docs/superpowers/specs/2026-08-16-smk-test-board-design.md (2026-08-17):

# SMK Test Board — Design

Date: 2026-08-16
Status: Approved, pending implementation plan

A 9-position macropad built around the Seeed XIAO ESP32-C6, existing as
hardware to validate the SMK firmware and the SMK Configurator end to end.
This repo owns the PCB; the firmware lives in `~/esp/SMK` and the editor in
`~/esp/smk_configurator`, and this design names the changes each of them
needs.

## Problem

SMK's ESP32-C6 support is written against one custom 59-key board, and parts
of it have never met hardware at all:

- **The RMT LED driver has never run.** `RGBLighting`/`LedStripDriverRMT` are
  implemented, but the reference board has no per-key RGB (the firmware's
  CLAUDE.md says so explicitly), so nothing has ever driven a real LED chain.
- **`BatteryMonitor` has never been checked against a battery.** Its own
  documentation states the mV→percentage curve is "not yet verified against a
  real board".
- **The matrix path has not been exercised on a C6 at all.** The BLE upload
  work of 2026-08-15 was validated against a bare XIAO ESP32-C6 with no
  switches attached: uploads and the GATT round trip were proven, but no key
  was ever pressed, so matrix scan, layers and HID typing remain untested on
  this MCU.

A small purpose-built board closes all three, and afterwards becomes the
fixture for encoder support.

### Out of scope

- **Rotary encoder firmware.** SMK cannot decode quadrature today: there is no
  encoder action in the keymap vocabulary, no `ActionToken` case, and no
  decoder. The encoder is *wired* here and read in a later project (§10).
- Per-key RGB (see §3 for why the LEDs are not under the switches).
- Any case, plate, or enclosure.

## Design overview

1. Matrix and pin map
2. Rotary encoder
3. LED chain
4. Power and battery
5. KiCad project and mechanical
6. Firmware: a new board configuration
7. Configurator: a `KeyboardDesign`
8. Bill of materials and fabrication
9. Testing and acceptance
10. Phase 2: encoder support

## 1. Matrix and pin map

A **3×3 matrix**: 8 Gateron low-profile switches plus the EC11's integrated
push switch, which occupies the row 0 / col 2 position.

Putting the encoder's push switch *in the matrix* rather than on its own GPIO
is deliberate and buys two things. The press works immediately as an ordinary
key you can bind in the configurator, months before any quadrature decoding
exists. And the matrix stays 3×3, which keeps the LED count at 9 — a hard
constraint, because `RGBLighting(gpioNum:rowCount:colCount:)` allocates
exactly `rowCount × colCount` LEDs.

| Function | XIAO pad | GPIO |
|---|---|---|
| ROW0–ROW2 (sense, pull-down) | D1, D2, D3 | 1, 2, 21 |
| COL0–COL2 (strobe, push-pull) | D4, D5, D6 | 22, 23, 16 |
| Encoder A / B | D7, D8 | 17, 19 |
| LED data | D9 | 20 |
| VBAT sense | D0 (A0) | 0 (ADC1_CH0) |
| Spare / test point | D10 | 18 |

Pin numbering is the XIAO ESP32-C6's published map (D0–D10 →
GPIO 0, 1, 2, 21, 22, 23, 16, 17, 19, 20, 18). GPIO 3, 14 and 15 are the
antenna switch, RF switch power and the onboard LED, and GPIO 4–7 are the
JTAG pads — none are exposed on the pads used here, so there is no conflict.

**Direction matches SMK's existing convention** (`colsAreDriven = 1`, columns
strobed push-pull, rows sensed with pull-downs), so the scan logic needs no
change. Diodes are therefore **anode to column, cathode to row** — the
direction current flows when a driven column is taken high.

Note that the reference board's GPIO map cannot be reused: it needs 17 pins
(5 rows + 12 columns) across GPIOs the XIAO does not expose.

## 2. Rotary encoder

An EC11 with integrated push switch. A and B go to GPIO17 and GPIO19, each
with a 100 nF capacitor to ground for contact debounce, and pulled up — the
ESP32-C6's internal pull-ups are sufficient, so **there are no external
pull-up resistors on this board and no footprints for them.** An earlier
revision of this section said they were "footprinted but may be left
unpopulated"; no such footprints were ever drawn, and the BOM's matching
"2 × 10 kΩ resistors" line was for parts that had nowhere to go. Corrected
rather than added to: this section's own reasoning is that the internal
pull-ups suffice, firmware does not read A/B until phase 2, and two more
footprints on a bring-up fixture is two more things to get wrong for no
benefit. If phase 2 finds the internal pull-ups marginal, add them then.

The push switch is wired as the matrix position at row 0 / col 2, with its own
diode like any other key.

**Nothing in the firmware reads A/B until phase 2.** They are wired, brought
to known pins, and left alone. This is the whole reason the encoder appears in
a board whose purpose is testing existing functionality.

## 3. LED chain

Nine **SK6812MINI-E** reverse-mount RGB LEDs, one under each matrix position,
chained with data in on GPIO20.

Per-key placement rather than an edge strip, because the sibling keyboard
project has already fabbed this exact part: `kbd.pretty` carries a proven
`SK6812MINI_E` footprint and `~/esp/SMK_Keyboard/reroute_led_field.py` exists
for routing a field of them. The layout risk that would otherwise argue for an
edge strip is already retired, and per-key is what the firmware's
`rowCount × colCount` model actually describes.

**Power comes from the battery/USB rail (VSYS, via the XIAO's BAT pad), not
from 3.3 V.** This corrects an earlier draft of this spec. SK6812MINI-E's
datasheet specifies **VDD 3.7–5.5 V**, so a 3.3 V rail is below minimum — the
sibling keyboard's own schematic note says exactly this, and feeds its chain
from VSYS rather than its 3.3 V LDO for both current and voltage reasons.

A **level shifter on DIN** carries the C6's 3.3 V data up to the LED rail,
matching the keyboard project's approach. Nine LEDs is few enough that a bare
3.3 V DIN would probably work, but "probably" is how intermittent first-LED
corruption gets designed in.

Each LED gets a 100 nF decoupling capacitor, with a 100 µF bulk capacitor at
the chain entry.

**Current budget:** 12 mA per channel × 3 × 9 LEDs = **324 mA at full white**.
Firmware must cap brightness rather than the board carrying that continuously.

**Known caveat, inherited from the part choice:** VSYS is the Li-ion cell, and
a discharging cell drops below SK6812MINI-E's 3.7 V minimum well inside its
normal range. The LEDs may misbehave on a low battery even with brightness
capped. That is a real limitation of per-key RGB on a single-cell board, not a
defect to fix here — the keyboard project carries the same note.

## 4. Power and battery

USB-C on the XIAO powers the board when tethered. For untethered BLE testing,
a single-cell Li-ion connects through a JST SH 2-pin connector, 1.0 mm pitch
(`J1`) on the PCB, which feeds the board's VSYS rail; the XIAO's onboard
charger handles charging. **Correction:** this used to say "JST-PH", which
is a different, 2.0 mm-pitch part; the footprint on the board
(`JST_SH_SM02B_2pin_Back`) has always been SH. See `docs/fabrication.md`'s
BOM note — a Li-ion pouch cell's common JST-PH pigtail will not mate with
this connector.

VSYS reaches the XIAO through **`J2`, a labelled 2-pin through-hole pad pair**
beside `U1`, and two short flying leads hand-soldered from it to the module's
BAT+/BAT− terminals. This is not a stylistic choice: those terminals are
solder pads on the module's **underside** and the XIAO seats on female
headers, so no PCB pad can ever mate with them — `XIAO_ESP32C6_HEADERS` is 14
pads with no BAT pad, and that is correct. Until `J2` existed, nothing tied
VSYS to the XIAO at all: `J1` fed the nine SK6812 VDD pins, their decoupling
caps, `C_BULK` and `U2`'s VCC, and the module was not in that circuit. The
board could not run untethered, the onboard charger never saw the cell, and on
USB with no cell fitted the whole LED chain and the level shifter were
unpowered.

Battery *monitoring* needs an **external divider, and this board now carries
one**: `R1`/`R2`, two 200 kΩ 0603s, VSYS → R1 → midpoint → R2 → GND with the
midpoint on `U1` pad 1 (D0 / GPIO0 / ADC1_CH0).

**Correction.** This section previously claimed the XIAO "already carries a
1:2 divider on A0" and that no external divider was needed. That is false for
this module. The on-module battery-sense divider belongs to the earlier XIAO
ESP32-C3/S3 generation; Seeed's battery-monitoring guidance for the **XIAO
ESP32-C6** calls for an external 200 kΩ/200 kΩ pair from the battery rail to
an ADC pin. Acting on the wrong premise, `build_nets()` referenced
`PIN["VBAT_SENSE"]` zero times — the pin drew a schematic port and nothing
else — so U1 pad 1 was left floating while firmware read ADC1_CH0 as a
battery voltage. Left alone it would have produced plausible-looking garbage
readings, and it would have misled the next board too.

200 kΩ is the value, not 100 k or 10 k: it halves VSYS exactly, and the whole
divider draws only ~10 µA at 4.2 V, which matters on the coin-sized cell this
board is for.

Firmware is unaffected and must not change: `vbatDividerRatio = 2` is exactly
right for a 1:2 divider, which is what R1/R2 are. The firmware assumption
("the board halves VBAT before it reaches the ADC pin") is now true of the
board, where before it was true of nothing.

## 5. KiCad project and mechanical

**The board is generated from Python, not drawn in the GUI**, following the
sibling projects: `~/esp/SMK_macro_pad/generate_macropad.py` (2156 lines) is a
base module that emits raw KiCad s-expressions, and
`generate_macropad_mini.py` imports it as `gm` to reuse its placement,
side-mirroring and clearance helpers. The `.kicad_sch`/`.kicad_pcb` files are
build artifacts of the generator, not the source of truth, and
`test_macropad_mini.py` (532 lines) is a pytest suite asserting geometric
properties — back clearance, cell clearance, hole clearance, grouping.

This project follows that shape: `generate_test_board.py` plus
`test_test_board.py`, writing `smk_test_board/smk_test_board.kicad_{pro,sch,pcb}`
in KiCad 8 format (which KiCad 9/10 read natively, as the siblings do),
plus an `fp-lib-table` and a project-local `kbd.pretty` so both footprint
libraries the board references resolve from `${KIPRJMOD}` and the project is
self-contained. (The `.kicad_pro` and the lib table were promised here but not
written for several revisions; their absence is what produced DRC's 46
`lib_footprint_issues` warnings.)

- Two layers, **76.0 × 113.16 mm** (as generated — the estimate here was
  "roughly 70 × 70 mm"; the board's real size falls out of the placement,
  since `build_pcb()` derives the outline from the extents of everything it
  places plus a 5 mm margin), keys on a 19.05 mm pitch.
- **Hot-swap sockets**, matching the available footprint and the sibling
  boards, so switches can be moved between projects.
- The XIAO mounts on two 1×7 female headers rather than being soldered to its
  castellated pads, so it can be removed. This is the same board used for
  firmware bring-up; keeping its USB port and BOOT/RESET buttons reachable
  matters more than 5 mm of height.
- Mounting holes: 4 × **M2** at the corners (2.4 mm NPTH, `gm.fp_hole` /
  `MountingHole_M2`). This said M3; the footprint the generator has always
  used is M2, and hardware must match the board, not the prose.

**Footprints: reuse, don't redraw.** `kbd.pretty` already carries
fab-proven footprints for everything except two parts:
`SW_Gateron_KS33_HS` (Gateron low profile *is* KS-33, hot-swap),
`SK6812MINI_E`, `D_SOD-123_Back`, `RC_0603`, `LED_0603`, `MountingHole_M2`,
`JST_SH_SM02B_2pin_Back`.

Only the **XIAO ESP32-C6** and the **EC11 encoder** footprints do not exist
anywhere in these repos and must be created. Those two — and only those two —
carry the "board arrives and nothing fits" risk, so **both must be printed at
1:1 and checked against the physical parts before fabrication.**

## 6. Firmware: a new board configuration

In `~/esp/SMK`:

- A new board branch in `Main.swift`'s `configJson`, with the §1 matrix, and
  its accompanying Kconfig option alongside the existing board choices.
- **`Sources/components/battery_adc.c` hardcodes IO4 / ADC1_CH4.** This board
  senses VBAT on GPIO0 / ADC1_CH0, so the ADC channel becomes per-board rather
  than fixed. This is a real change to shared firmware code, not a
  configuration value.
- `RGBLighting` is instantiated with `gpioNum: 20, rowCount: 3, colCount: 3`,
  and whatever Kconfig gate currently disables RGB on the reference board is
  enabled for this one.

## 7. Configurator: a `KeyboardDesign`

In `~/esp/smk_configurator`: a `KeyboardDesign` describing the 3×3 physical
layout with `matrix.rows = [1, 2, 21]`, `matrix.cols = [22, 23, 16]`, and
`colsAreDriven = 1`, plus a `keymap.json` for it. The design is editor-only —
the firmware never sees it — but its matrix block is what makes a written
`keymap.json` valid, so the GPIO numbers must match §1 exactly.

## 8. Bill of materials and fabrication

On hand: XIAO ESP32-C6, 8 × Gateron low-profile (KS-33) switches, 1 × EC11,
and **9 × 1N4148** diodes — one per matrix position, the encoder's push switch
included.

To source: 9 × SK6812MINI-E, 9 × Gateron KS-33 hot-swap sockets, 1 × level
shifter for the LED data line (same part the keyboard project uses), 2 × 1×7
female headers, 1 × JST SH 2-pin connector (1.0 mm pitch, **not** JST-PH),
**12 × 100 nF** capacitors (9 for
LED decoupling, 2 for encoder debounce, 1 for the level shifter U2's own VCC),
1 × 100 µF bulk capacitor at the LED
chain entry, 2 × 200 kΩ resistors (the VBAT sense divider, §4), 4 × **M2**
standoffs, and low-profile keycaps. Also two short lengths of insulated wire
for the `J2` → XIAO BAT+/BAT− flying leads (§4). There are **no** 10 kΩ
encoder pull-ups: see §2.

The sibling `~/esp/SMK_macro_pad/smk_macropad/JLCPCB_Sourcing_Report.md` is
the precedent for part selection and should be consulted for the level
shifter and passives rather than choosing fresh parts.

Fabrication is JLCPCB, bare boards only — hand assembly, no PCBA. At this
part count and with through-hole switches, assembly service buys nothing.

## 9. Testing and acceptance

The board is finished when each of these passes on it:

1. **Matrix** — every one of the 9 positions registers, including the encoder
   press, with no ghosting when three keys in an L are held.
2. **Layers** — an `mo:` binding on one key changes what the others emit while
   held; a `tg:` binding latches.
3. **BLE HID** — the board types into a Mac over BLE.
4. **Keymap upload** — the configurator's DEV pane shows "Connected via BLE",
   an upload completes, and a remapped key emits its new value. This is the
   check the 2026-08-15 BLE work could not perform, having no switches.
5. **Persistence** — the remap survives a power cycle.
6. **RGB** — the LED chain lights and animates. First hardware validation of
   the RMT driver.
7. **Battery** — on battery, the Mac's Bluetooth panel shows a plausible
   percentage that falls as the cell discharges. First hardware validation of
   `BatteryMonitor`.
8. **Multi-host bonding** — pair to two Macs and confirm both reconnect
   without re-pairing, exercising `CONFIG_BT_NIMBLE_MAX_BONDS = 4`.

Checks 1–3 are firmware; 4–5 are the configurator; 6–8 are the subsystems this
board exists to reach.

## 10. Phase 2: encoder support

Once the board is populated, encoder support becomes its own project spanning
both software repos, and it is genuinely three changes, not one:

- **Firmware:** quadrature decoding of GPIO17/19, and an encoder action in the
  keymap vocabulary.
- **Keymap schema:** a new `ActionToken` case and cell syntax, which is a
  hand-synced contract between the firmware's `LayerEngine` and the app's
  `ActionToken` — the same coupling the repos already track by hand.
- **Configurator:** UI to bind clockwise and counter-clockwise actions, which
  do not fit the existing per-key grid model.

It gets its own spec and plan. The wiring in §2 exists so that work starts
with hardware already in hand.

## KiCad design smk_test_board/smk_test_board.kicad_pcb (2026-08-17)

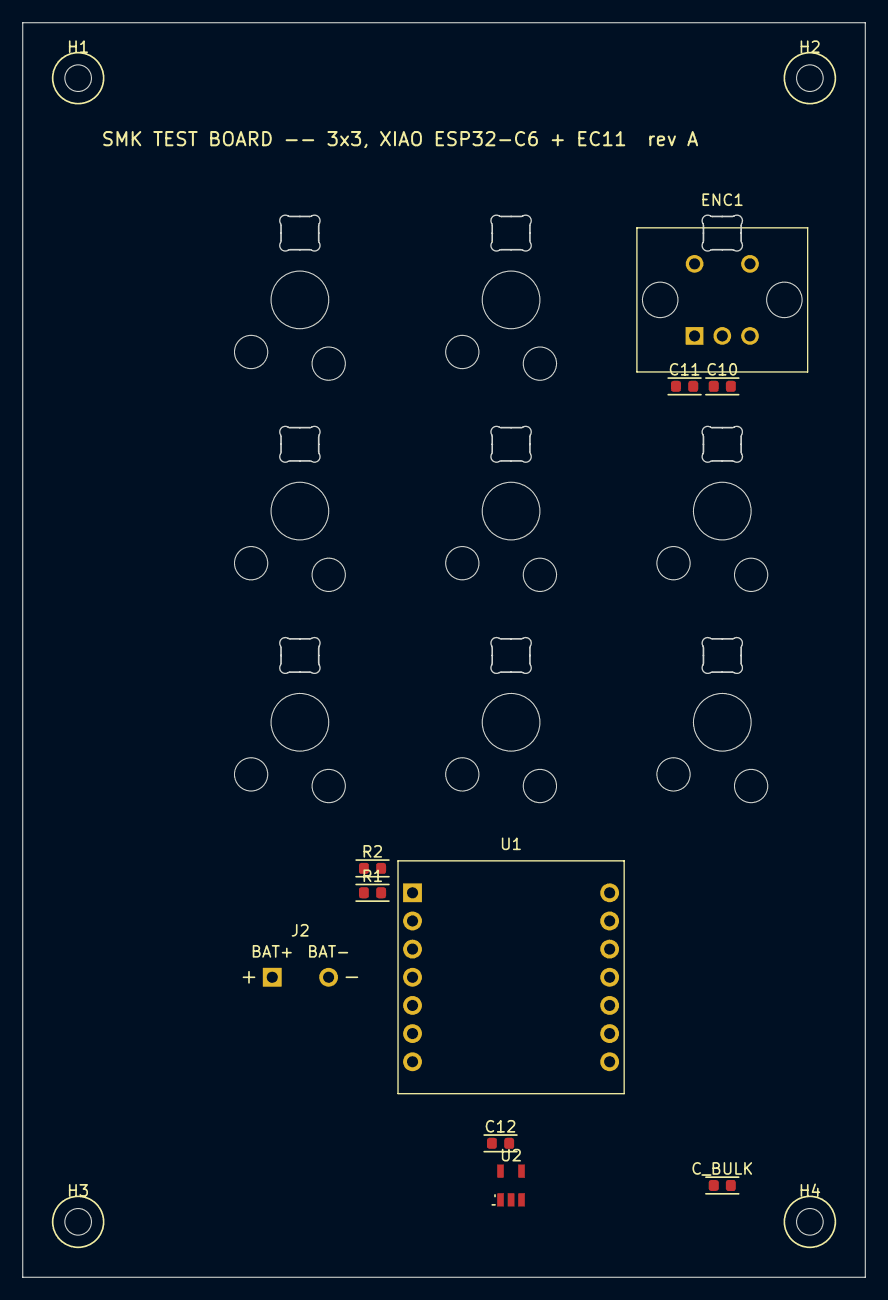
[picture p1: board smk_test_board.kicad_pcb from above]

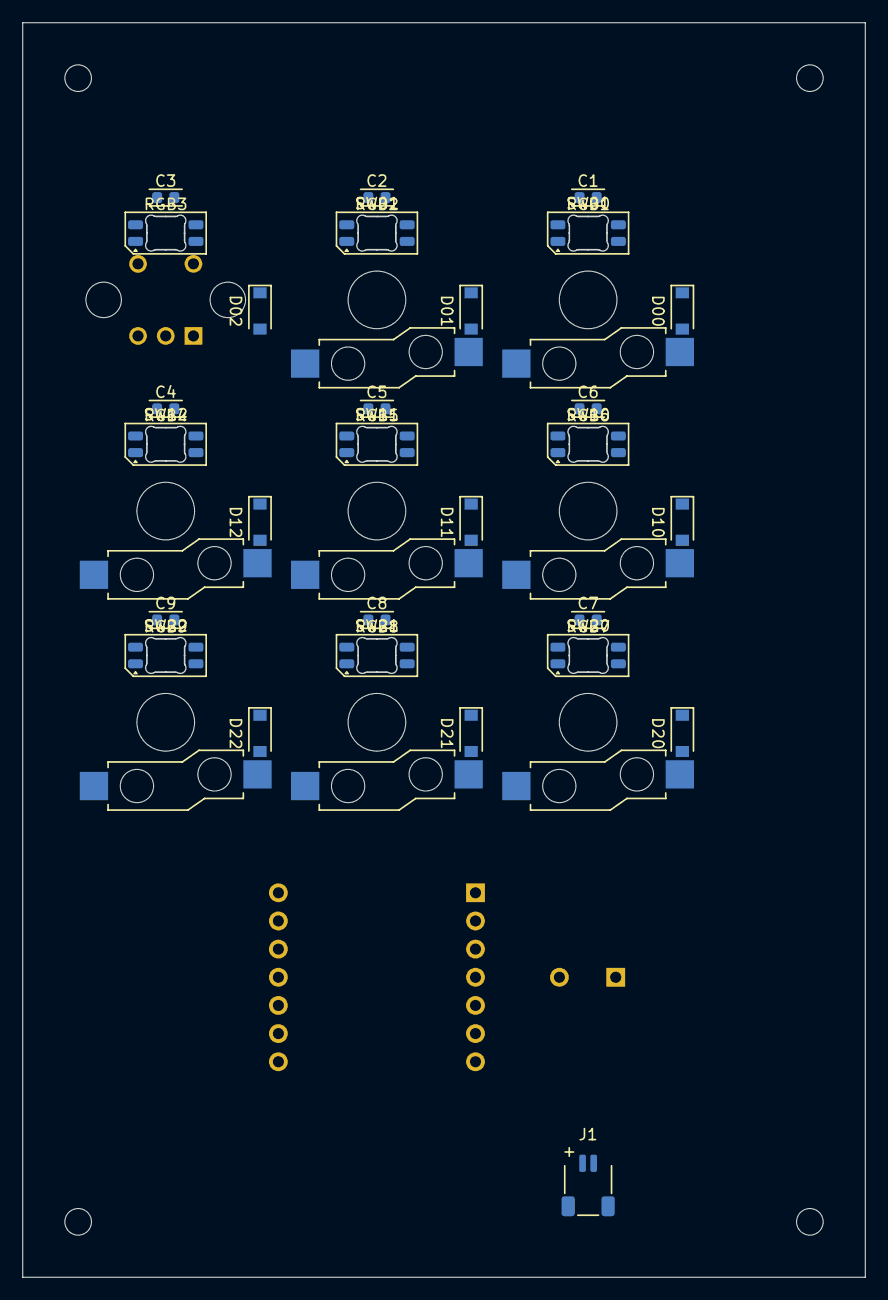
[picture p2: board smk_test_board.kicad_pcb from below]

Board: 2 copper layers, 76.0 x 113.2 mm, 50 parts (36 on the bottom side), 30 nets, no tracks yet.

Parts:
C1, C2, C3, C4, C5, C6, C7, C8, C9, C10, C11, C12: 100n; RC_0603
C_BULK: 100u; RC_0603
D00, D01, D02, D10, D11, D12, D20, D21, D22: 1N4148W; D_SOD-123_Back
ENC1: EC11 (VERIFY before fab); EC11_VERTICAL
H1, H2, H3, H4: M2; MountingHole_M2
J1: Battery JST-SH; JST_SH_SM02B_2pin_Back
J2: BAT+ / BAT- flying leads; BAT_WIRE_PADS
R1, R2: 200k; RC_0603
RGB1, RGB2, RGB3, RGB4, RGB5, RGB6, RGB7, RGB8, RGB9: SK6812MINI-E; SK6812MINI_E
SW00, SW01, SW10, SW11, SW12, SW20, SW21, SW22: KS-2P02B01-02; SW_Gateron_KS33_HS
U1: XIAO_ESP32C6; XIAO_ESP32C6_HEADERS
U2: SN74AHCT1G125DBVR; SOT-23-5

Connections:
COL0: SW00.1, SW10.1, SW20.1, U1.5
COL1: SW01.1, SW11.1, SW21.1, U1.6
COL2: ENC1.4, SW12.1, SW22.1, U1.7
ENC_A: C10.1, ENC1.1, U1.8
ENC_B: C11.1, ENC1.3, U1.9
GND: C1.2, C2.2, C3.2, C4.2, C5.2, C6.2, C7.2, C8.2, C9.2, C10.2, C11.2, C12.2, C_BULK.2, ENC1.2, J1.2, J2.2, R2.2, RGB1.3, RGB2.3, RGB3.3, RGB4.3, RGB5.3, RGB6.3, RGB7.3, RGB8.3, RGB9.3, U1.13, U2.1, U2.3
LEDD0: U1.10, U2.2
LEDD1: RGB1.4, U2.4
LEDD2: RGB1.2, RGB2.4
LEDD3: RGB2.2, RGB3.4
LEDD4: RGB3.2, RGB4.4
LEDD5: RGB4.2, RGB5.4
LEDD6: RGB5.2, RGB6.4
LEDD7: RGB6.2, RGB7.4
LEDD8: RGB7.2, RGB8.4
LEDD9: RGB8.2, RGB9.4
ROW0: D00.1, D01.1, D02.1, U1.2
ROW1: D10.1, D11.1, D12.1, U1.3
ROW2: D20.1, D21.1, D22.1, U1.4
SW00_N: D00.2, SW00.2
SW01_N: D01.2, SW01.2
SW02_N: D02.2, ENC1.5
SW10_N: D10.2, SW10.2
SW11_N: D11.2, SW11.2
SW12_N: D12.2, SW12.2
SW20_N: D20.2, SW20.2
SW21_N: D21.2, SW21.2
SW22_N: D22.2, SW22.2
VBAT_SENSE: R1.2, R2.1, U1.1
VSYS: C1.1, C2.1, C3.1, C4.1, C5.1, C6.1, C7.1, C8.1, C9.1, C12.1, C_BULK.1, J1.1, J2.1, R1.1, RGB1.1, RGB2.1, RGB3.1, RGB4.1, RGB5.1, RGB6.1, RGB7.1, RGB8.1, RGB9.1, U2.5

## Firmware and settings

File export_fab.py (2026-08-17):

#!/usr/bin/env python3
"""Export JLCPCB-ready Gerbers + drill files for the SMK test board.

Structure copied from ~/esp/SMK_Keyboard/smk_kbd_rp2040/export_fab.py (the
zone-fill / plot-gerbers / write-drill / zip pipeline that ecosystem uses),
adapted to drive kicad-cli instead of KiCad's bundled pcbnew module -- this
board's DRC/export work already runs kicad-cli directly (see
docs/fabrication.md), so staying on one tool avoids needing a second Python
interpreter. Also: this board has no copper pours, so there is nothing to
zone-fill; the check below exists so a future revision that adds a GND pour
doesn't silently ship unfilled zones.

Run with the system/venv Python (this only shells out to kicad-cli, no
pcbnew import needed):
  python3 export_fab.py

kicad-cli location:
  macOS default install: /Applications/KiCad/KiCad.app/Contents/MacOS/kicad-cli
  Override with the KICAD_CLI env var if it's elsewhere or already on PATH.

Output: gerbers/ (gitignored) + smk_test_board_gerbers.zip (gitignored,
*.zip) at the repo root -- upload the zip to JLCPCB.
"""
import os
import shutil
import subprocess
import sys
import zipfile

HERE = os.path.dirname(os.path.abspath(__file__))
BOARD = os.path.join(HERE, "smk_test_board", "smk_test_board.kicad_pcb")
OUT = os.path.join(HERE, "gerbers")
ZIP_PATH = os.path.join(HERE, "smk_test_board_gerbers.zip")

_DEFAULT_MAC_CLI = "/Applications/KiCad/KiCad.app/Contents/MacOS/kicad-cli"
KICAD_CLI = (
    os.environ.get("KICAD_CLI")
    or shutil.which("kicad-cli")
    or (_DEFAULT_MAC_CLI if os.path.exists(_DEFAULT_MAC_CLI) else None)
)
if not KICAD_CLI:
    raise SystemExit(
        "kicad-cli not found on PATH and KICAD_CLI is not set. "
        f"On macOS it's normally at {_DEFAULT_MAC_CLI}."
    )


def run(*args):
    cmd = [KICAD_CLI, *args]
    print("+", " ".join(cmd))
    subprocess.run(cmd, check=True)


if not os.path.isfile(BOARD):
    raise SystemExit(f"board not found: {BOARD}")

os.makedirs(OUT, exist_ok=True)

# 1. Zone-fill check. This is a bare 2-layer board shipped ratsnest-only
# (see docs/fabrication.md) -- there is no GND pour or any other copper
# zone to fill. Fail loudly rather than silently exporting unfilled
# copper if that ever changes; the sibling generator's zone-fill step
# would need porting here too if it does.
with open(BOARD, "r", encoding="utf-8") as f:
    board_text = f.read()
if "(zone " in board_text or "(zone\n" in board_text:
    raise SystemExit(
        "board now has one or more zones -- this script has no zone-fill "
        "step. Port the fill-zones-then-save step from "
        "~/esp/SMK_Keyboard/smk_kbd_rp2040/export_fab.py before exporting."
    )
print("no copper zones on this board -- zone-fill step is a no-op, as expected")

# 2. Gerbers. Layer set matches the RP2040 sibling's export_fab.py minus
# the inner copper layers this board doesn't have (it's 2-layer, not 4).
GERBER_LAYERS = ",".join([
    "F.Cu", "B.Cu",
    "F.Mask", "B.Mask",
    "F.Silkscreen", "B.Silkscreen",
    "F.Paste", "B.Paste",
    "Edge.Cuts",
])
run(
    "pcb", "export", "gerbers",
    "--output", OUT + os.sep,
    "--layers", GERBER_LAYERS,
    "--subtract-soldermask",
    BOARD,
)
print("gerbers plotted")

# 3. Drill files (Excellon, metric, PTH/NPTH split -- the board has both).
#
# PTH: the 14 XIAO header pads (U1), the EC11's 5 signal pins (ENC1), and the
# 2 battery flying-lead pads (J2) -- 21 plated holes. The switch, diode and
# LED pads are all SMD and drill nothing; an earlier version of this comment
# said "switch/diode/LED/header pads are PTH", which is wrong for three of
# those four.
#
# NPTH: 30 unplated holes -- the four M2 corner mounting holes (2.4mm,
# gm.fp_hole), the EC11's two 3.2mm mounting-post legs, and the Gateron
# hot-swap sockets' own mechanical holes (one 5.2mm centre plus two 3.0mm
# switch-leg holes per socket, x8 sockets = 24). Cross-check against
# gerbers/drill-report.txt after every export: 21 plated / 30 unplated.
#
# Neither count includes the nine SK6812MINI-E light windows: those are milled
# Edge.Cuts slots, not drilled holes, and they leave the board on the
# Edge_Cuts gerber rather than in either drill file. If a future revision ever
# shows an empty/near-empty Edge_Cuts layer, the LEDs have lost their windows.
#
# Also emit a map + report for JLCPCB's reviewers to cross-check.
run(
    "pcb", "export", "drill",
    "--output", OUT + os.sep,
    "--format", "excellon",
    "--drill-origin", "absolute",
    "--excellon-units", "mm",
    "--excellon-zeros-format", "decimal",
    "--excellon-separate-th",
    "--generate-map",
    "--map-format", "gerberx2",
    "--generate-report",
    "--report-path", os.path.join(OUT, "drill-report.txt"),
    BOARD,
)
print("drill files written")

# 4. Zip for JLCPCB upload.
with zipfile.ZipFile(ZIP_PATH, "w", zipfile.ZIP_DEFLATED) as z:
    for name in sorted(os.listdir(OUT)):
        z.write(os.path.join(OUT, name), name)
print(f"wrote {ZIP_PATH} -- upload this to JLCPCB")

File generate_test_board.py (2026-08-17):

#!/usr/bin/env python3
"""SMK Test Board -- 3x3 macropad on a Seeed XIAO ESP32-C6.

Hardware for validating the parts of SMK that have never met a board: the
matrix path on a C6, the RMT LED driver, and BatteryMonitor. See
docs/superpowers/specs/2026-08-16-smk-test-board-design.md.

Like its siblings in ~/esp/SMK_macro_pad, the .kicad_sch/.kicad_pcb this
writes are BUILD ARTIFACTS. Edit this file and re-run; never hand-edit the
outputs. Never run KiCad's "Update Footprints from Library" on the result.

The geometry and s-expression helpers come from generate_macropad.py in the
sibling repo rather than being forked -- that module's own docstring records
what forking cost the last time.

WHAT IS UNVERIFIED
  The XIAO ESP32-C6 and EC11 footprints are drawn here for the first time
  (Tasks 3 and 4) and have never been fabricated. Print at 1:1 and check
  against physical parts before ordering.
  SK6812MINI-E runs from VSYS (3.0-4.2V on battery); its datasheet minimum
  is 3.7V, so the LEDs may misbehave on a low cell. Inherited from the part
  choice, not a defect here.
"""
import json
import math
import os
import re
import sys

_SIBLING = os.path.expanduser("~/esp/SMK_macro_pad")
if not os.path.isdir(_SIBLING):
    raise SystemExit(
        f"sibling generator not found at {_SIBLING}\n"
        "This project reuses generate_macropad.py's helpers rather than "
        "forking them; clone ~/esp/SMK_macro_pad next to this repo."
    )
sys.path.insert(0, _SIBLING)
import generate_macropad as gm  # noqa: E402

PROJ = "smk_test_board"
PRJDIR = os.path.join(os.path.dirname(os.path.abspath(__file__)), PROJ)

ROWS = 3
COLS = 3
LED_COUNT = ROWS * COLS
KEY_PITCH = 19.05

# Origin of the key field on the board, in mm.
KEY_X0 = 25.0
KEY_Y0 = 25.0

# The contract with ~/esp/SMK's board config and the configurator's
# KeyboardDesign. All three must agree; see the spec's section 1.
PIN = {
    "ROW0": 1, "ROW1": 2, "ROW2": 21,
    "COL0": 22, "COL1": 23, "COL2": 16,
    "ENC_A": 17, "ENC_B": 19,
    "LED_DATA": 20,
    "VBAT_SENSE": 0,
    "SPARE": 18,
}


def key_xy(r, c):
    """Centre of the key at (row, col), in board mm."""
    return (KEY_X0 + c * KEY_PITCH, KEY_Y0 + r * KEY_PITCH)


# ============================================================ NETLIST ======
# Logical pad names, not footprint pad numbers -- "A"/"K" for diodes, "1"/"2"
# for switches, "VDD"/"GND"/"DIN"/"DOUT" for the LEDs. build_sch() translates
# through PAD_MAP on the way out. Most refs (XIAO pads, the Gateron switches,
# the EC11, the JST connector) already use numeric footprint pad numbers
# directly as their logical name, so PAD_MAP only needs entries for the
# footprints where that isn't true.
PAD_MAP = {
    # logical name -> footprint pad number, per the proven footprints
    "SK6812MINI_E": {"VDD": "1", "DOUT": "2", "GND": "3", "DIN": "4"},
    # D_SOD-123_Back: pad 1 = K, pad 2 = A. Settled from the sibling's own
    # fp_diode(ref, x, y, rot, n_k, n_a, ...) -- cathode net is its FIRST
    # net parameter, wired to pad 1. (generate_macropad.py:1485 records
    # this exact class of bug having shipped there once already.)
    "D_SOD-123_Back": {"K": "1", "A": "2"},
    # SOT-23-5: SN74AHCT1G125DBVR pinout (datasheet SCLS504E) --
    # 1 OE#(active-low) 2 A(in) 3 GND 4 Y(out) 5 VCC
    "SOT-23-5": {"OE#": "1", "A": "2", "GND": "3", "Y": "4", "VCC": "5"},
}


def build_nets():
    """net name -> [(ref, logical pad), ...]

    Diode anode to column *through the switch*, cathode to row: the only
    conducting path is COL -> SW -> D -> ROW, which is what colsAreDriven=1
    with pull-down row sensing requires.

    Position (0, 2) has no SW02 -- the EC11's integrated push switch
    occupies that matrix position instead (see the design spec's §2), wired
    at the bottom of this function alongside the rest of the encoder: ENC1
    pad 4 takes the COL2 side, pad 5 takes the SW02_N (diode-anode) side.
    D02 itself still exists like any other matrix diode.
    """
    nets = {}

    def add(net, ref, pad):
        nets.setdefault(net, []).append((ref, pad))

    for r in range(ROWS):
        add(f"ROW{r}", "U1", str(2 + r))          # XIAO pads 2,3,4
    for c in range(COLS):
        add(f"COL{c}", "U1", str(5 + c))          # XIAO pads 5,6,7

    for r in range(ROWS):
        for c in range(COLS):
            d = f"D{r}{c}"
            add(f"ROW{r}", d, "K")
            if (r, c) == (0, 2):
                continue          # EC11 push switch takes this position
            sw = f"SW{r}{c}"
            add(f"COL{c}", sw, "1")
            add(f"SW{r}{c}_N", sw, "2")           # switch -> diode anode
            add(f"SW{r}{c}_N", d, "A")

    # LED chain: level shifter (SN74AHCT1G125DBVR, SOT-23-5, single-gate
    # buffer -- same part the sibling keyboard project uses) drives RGB1,
    # then each DOUT feeds the next DIN. OE# tied to GND permanently
    # enables it; VCC from VSYS (not +3V3) so AHCT's 2.0V input threshold
    # keeps margin against the C6's 3.3V drive across VSYS's whole range.
    add("LEDD0", "U1", "10")                      # GPIO20 -> shifter in
    add("LEDD0", "U2", "A")                        # shifter input
    add("GND", "U2", "OE#")                        # permanently enabled
    add("GND", "U2", "GND")
    add("LEDD1", "U2", "Y")                         # shifter output -> RGB1 DIN
    add("VSYS", "U2", "VCC")
    for i in range(1, LED_COUNT + 1):
        add(f"LEDD{i}", f"RGB{i}", "DIN")
        if i < LED_COUNT:
            add(f"LEDD{i + 1}", f"RGB{i}", "DOUT")
        add("VSYS", f"RGB{i}", "VDD")             # NOT +3V3: VDD min is 3.7V
        add("GND", f"RGB{i}", "GND")
        # Local 100nF decoupling per LED (C1..C9, one per RGBi), matching
        # the SK6812MINI-E datasheet's own recommended application circuit
        # -- and the sibling keyboard project's C100-C158, added there for
        # the same reason (an earlier revision of that board had only one
        # bulk cap at the chain's start, LEDs away from the far end).
        # Controller review round 1 on Task 6: this board's build_nets()
        # originally wired none of these at all; fixed here.
        add("VSYS", f"C{i}", "1")
        add("GND", f"C{i}", "2")

    add("ENC_A", "U1", "8")
    add("ENC_A", "ENC1", "1")
    add("ENC_B", "U1", "9")
    add("ENC_B", "ENC1", "3")
    add("GND", "ENC1", "2")
    add("COL2", "ENC1", "4")                      # push switch: COL2 side
    add("SW02_N", "ENC1", "5")                    # push switch: diode side
    add("SW02_N", "D02", "A")                     # D02 anode meets the switch

    # Encoder debounce: 100nF A-to-GND and B-to-GND, per the design spec's
    # §2 ("each with a 100nF capacitor to ground for contact debounce").
    # Also missing from the original build_nets(); fixed alongside the LED
    # decoupling caps above.
    add("ENC_A", "C10", "1")
    add("GND", "C10", "2")
    add("ENC_B", "C11", "1")
    add("GND", "C11", "2")

    # U2's own local decoupling. Controller review (final wave): the level
    # shifter had nothing on VCC at all -- the nearest cap was C_BULK, 19mm
    # away down the bottom edge, which is a bulk reservoir, not local
    # decoupling for a part switching an 800kHz-ish WS2812 data line.
    add("VSYS", "C12", "1")
    add("GND", "C12", "2")

    add("VSYS", "J1", "1")
    add("GND", "J1", "2")
    # Bulk cap at the LED chain entry. Wired through build_nets() like every
    # other part rather than having its nets passed straight to fp_0603():
    # build_sch() places parts from this dict, so anything that skips it is
    # invisible to the schematic (and to any schematic-derived BOM or
    # netlist). C_BULK, C1-C11 and C10/C11 were all missing from the
    # schematic for exactly that reason until the final review wave.
    add("VSYS", "C_BULK", "1")
    add("GND", "C_BULK", "2")

    # ---- battery: JST -> VSYS -> two flying leads -> the XIAO ------------
    # J2 is a labelled 2-pin THROUGH-HOLE pad pair beside U1 (see
    # _fp_bat_pads()'s docstring for why no PCB pad can reach the XIAO's own
    # underside BAT+/BAT- terminals). Without it VSYS has no source and no
    # sink at the module: the board cannot run untethered, the XIAO's
    # onboard charger never sees the JST cell, and on USB with no cell
    # fitted the LED chain and level shifter are unpowered.
    add("VSYS", "J2", "1")                        # BAT+ flying lead
    add("GND", "J2", "2")                         # BAT- flying lead

    # ---- VBAT sense divider ---------------------------------------------
    # Two 200k 0603s: VSYS -> R1 -> VBAT_SENSE (midpoint) -> R2 -> GND, with
    # the midpoint on U1 pad 1 (D0 / GPIO0 / ADC1_CH0).
    #
    # The design spec's Sec.4 used to claim the XIAO ESP32-C6 "already
    # carries a 1:2 divider on A0" and that no external divider was needed.
    # That is false -- it is the XIAO ESP32-C3/S3 generation that carries an
    # on-module divider; Seeed's own ESP32-C6 battery-monitoring guidance
    # calls for an EXTERNAL 200k/200k pair from BAT to an ADC pin. The spec
    # has been corrected. Before this, PIN["VBAT_SENSE"] existed and drew a
    # schematic port, but build_nets() referenced it zero times: U1 pad 1
    # was a floating input that firmware read as a battery voltage.
    #
    # 200k/200k (not 100k or 10k): halves VSYS exactly, which is what
    # firmware's `vbatDividerRatio = 2` already assumes -- firmware is
    # correct as written and must not change -- while drawing only ~10uA at
    # 4.2V, which matters on the coin-sized cell this board is for.
    add("VSYS", "R1", "1")
    add("VBAT_SENSE", "R1", "2")
    add("VBAT_SENSE", "R2", "1")
    add("GND", "R2", "2")
    add("VBAT_SENSE", "U1", "1")                  # D0 / GPIO0 / ADC1_CH0

    # U1 pad 12 (+3V3, the XIAO's own regulated logic rail) is left
    # unwired: nothing on this board consumes regulated 3.3V -- the LEDs
    # are deliberately on VSYS (see above) and the level shifter is now a
    # single VSYS-rail part, so there is no +3V3 net at all.
    add("GND", "U1", "13")
    return nets


# Two-pin parts that have no hand-drawn block of their own in build_sch().
# ref -> (lib symbol, value, footprint, PCB side).
#
# This registry is the fix for a whole class of bug, not a convenience: the
# schematic used to be assembled purely from hand-written per-block code, so
# every part added to build_nets()/build_pcb() without someone also editing
# build_sch() simply never appeared in it. That is how C1-C9, C10, C11 and
# C_BULK -- 12 real, placed, netted parts -- ended up on the PCB and not in
# the schematic, making any schematic-derived BOM or netlist wrong by 12
# parts and `--schematic-parity` DRC unusable. build_sch() now auto-places
# everything listed here, build_pcb() reads its values/footprints from the
# same table, and test_schematic_has_every_part_the_pcb_has asserts the two
# documents carry the identical ref set.
AUX_PARTS = {}
for _i in range(1, LED_COUNT + 1):
    AUX_PARTS[f"C{_i}"] = ("C_kbd", "100n", "RC_0603", "B")   # per-LED decoupling
AUX_PARTS["C10"] = ("C_kbd", "100n", "RC_0603", "F")          # ENC_A debounce
AUX_PARTS["C11"] = ("C_kbd", "100n", "RC_0603", "F")          # ENC_B debounce
AUX_PARTS["C12"] = ("C_kbd", "100n", "RC_0603", "F")          # U2 VCC decoupling
AUX_PARTS["C_BULK"] = ("C_kbd", "100u", "RC_0603", "F")       # LED chain entry
AUX_PARTS["R1"] = ("R_kbd", "200k", "RC_0603", "F")           # VBAT divider high
AUX_PARTS["R2"] = ("R_kbd", "200k", "RC_0603", "F")           # VBAT divider low
AUX_PARTS["J2"] = ("Conn_BAT2_tb", "BAT+ / BAT- flying leads",
                   "BAT_WIRE_PADS", "F")
del _i


# ============================================================ SCHEMATIC ====
# Own lib_symbols, built from generate_macropad's exposed primitives
# (lib_header, sym_pin, sym_inst, sch_wire, sch_glabel, sch_nc, sch_text,
# sch_frame, power_inst, g, NU, U, FONT, POWER_SYMS/POWER_NETS) rather than
# gm.build_lib_symbols(), which would drag in RP2040/RM2/USB-C symbols this
# board has none of. `boxsym` and the per-net power-symbol block are small
# (~15 line) local re-derivations of code gm keeps nested inside its own
# build_lib_symbols() and therefore doesn't expose; everything else below is
# gm's own top-level helpers used directly.

FOOTPRINT_LIB = "smk_test_board"


def _fp(name):
    return f"{FOOTPRINT_LIB}:{name}"


def _boxsym(name, refpfx, value, w, pins):
    """A rectangular multi-pin symbol body. `pins` is a list of
    (electrical_type, x, y, rot, pin_name, pin_number). Mirrors the shape of
    gm's own (nested, unexported) boxsym()."""
    top = max(p[2] for p in pins) + 2.54
    bot = min(p[2] for p in pins) - 2.54
    s = gm.lib_header(name, refpfx, value, hide_pin_names=False)
    s += f'''      (symbol "{name}_0_1"
        (rectangle (start {gm.g(-w / 2)} {gm.g(top)}) (end {gm.g(w / 2)} {gm.g(bot)})
          (stroke (width 0.254) (type default)) (fill (type background)))
      )
      (symbol "{name}_1_1"
'''
    for (pt, x, y, rot, pn, num) in pins:
        s += gm.sym_pin(pt, x, y, rot, pn, str(num)) + "\n"
    s += "      )\n    )\n"
    return s


def _two_pin_named(name, refpfx, value, body, pin1, pin2, pin_x=3.81, length=1.27):
    """Like gm's two_pin_sym(), but with caller-chosen (name, number) pairs
    instead of two_pin_sym's hardcoded "1"/"2" -- needed wherever the
    logical pad name build_nets() uses isn't itself the footprint pad
    number (the level shifter's IN/OUT) or where a friendlier pin name is
    worth having alongside the real pad number (the diode's A/K)."""
    s = gm.lib_header(name, refpfx, value)
    s += f'      (symbol "{name}_0_1"\n{body}      )\n'
    s += f'      (symbol "{name}_1_1"\n'
    s += gm.sym_pin("passive", -pin_x, 0, 0, pin1[0], pin1[1], length=length) + "\n"
    s += gm.sym_pin("passive", pin_x, 0, 180, pin2[0], pin2[1], length=length) + "\n"
    s += "      )\n    )\n"
    return s


def _power_symbols():
    """GND/+3V3/VSYS power ports, in the shape gm.power_inst()'s hardcoded
    "kbd:{net}" lib_id expects. Copied from gm's own inline block (not a
    top-level function there) and trimmed to the three rails this board
    actually has."""
    L = []
    for pname, updown in gm.POWER_SYMS:
        if pname not in ("GND", "+3V3", "VSYS"):
            continue
        if updown == "up":
            body = ('        (polyline (pts (xy 0 0) (xy 0 2.54)) (stroke (width 0) (type default)) (fill (type none)))\n'
                    '        (polyline (pts (xy -0.762 1.27) (xy 0 2.54)) (stroke (width 0) (type default)) (fill (type none)))\n'
                    '        (polyline (pts (xy 0 2.54) (xy 0.762 1.27)) (stroke (width 0) (type default)) (fill (type none)))\n')
            prot, vy = 90, 3.81
        else:
            body = ('        (polyline (pts (xy 0 0) (xy 0 -1.27) (xy 1.27 -1.27) (xy 0 -2.54) '
                    '(xy -1.27 -1.27) (xy 0 -1.27)) (stroke (width 0) (type default)) (fill (type none)))\n')
            prot, vy = 270, -3.81
        L.append(
            f'    (symbol "kbd:{pname}" (power) (pin_names (offset 0)) (exclude_from_sim no) (in_bom no) (on_board yes)\n'
            f'      (property "Reference" "#PWR" (at 0 -6.35 0) (effects (font (size 1.27 1.27)) (hide yes)))\n'
            f'      (property "Value" "{pname}" (at 0 {vy:g} 0) {gm.FONT})\n'
            f'      (property "Footprint" "" (at 0 0 0) (effects (font (size 1.27 1.27)) (hide yes)))\n'
            f'      (property "Datasheet" "" (at 0 0 0) (effects (font (size 1.27 1.27)) (hide yes)))\n'
            f'      (property "Description" "" (at 0 0 0) (effects (font (size 1.27 1.27)) (hide yes)))\n'
            f'      (symbol "{pname}_0_1"\n{body}      )\n'
            f'      (symbol "{pname}_1_1"\n'
            f'        (pin power_in line (at 0 0 {prot}) (length 1.27) hide\n'
            f'          (name "{pname}" {gm.FONT})\n'
            f'          (number "1" {gm.FONT})\n'
            f'        )\n'
            f'      )\n    )\n')
    return "\n".join(L)
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

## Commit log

2026-08-16 Add SMK test board design doc
    A 9-position macropad on the XIAO ESP32-C6, built to validate the parts of
    SMK that have never met hardware: the RMT LED driver (the reference board
    has no RGB), BatteryMonitor (documented as unverified against a real
    board), and the matrix path on a C6 at all -- the BLE upload work was
    proven against a bare dev board with no switches attached.
    The encoder is wired but not read: SMK cannot decode quadrature today, so
    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
2026-08-16 Correct the spec against the sibling KiCad projects
    Three assumptions were wrong, all found by reading ~/esp/SMK_macro_pad and
    ~/esp/SMK_Keyboard rather than by thinking harder:
    - Boards here are generated from Python (generate_macropad.py emits raw
    s-expressions, with a pytest suite asserting clearances); they are not
    drawn in the GUI. This project follows that shape.
    - Gateron low profile is KS-33 and its hot-swap footprint is already
    fab-proven in kbd.pretty, as is SK6812MINI_E. Only the XIAO and EC11
    footprints actually need creating.
    - SK6812MINI-E specs VDD 3.7-5.5V, so the earlier 'run the LEDs at 3.3V'
    decision was below the part's minimum. Power now comes from VSYS with a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
2026-08-16 Add the SMK test board implementation plan
    Ten tasks across three repos: a Python-generated KiCad board following the
    sibling projects' conventions, then the firmware board config and the
    configurator design that make it usable.
    The two footprints that do not already exist -- XIAO ESP32-C6 and EC11 --
    each carry a manual 1:1 print check against the physical part, since a
    wrong footprint is only discoverable after fabrication.
2026-08-16 Copy the proven footprints into a local library
2026-08-16 Fix MountingHole_M2 pad count to 1 to catch corruption
    The footprint has one non-plated through-hole pad. Previously set to 0,
    which made the test permissive to truncation — an empty file would pass
    all checks. Now validates that the pad exists as expected.
    [test_footprints.py]
2026-08-16 Add the generator skeleton and pin-map contract tests
    The generator imports the sibling ~/esp/SMK_macro_pad helpers rather than
    forking them. The tests verify the pin-map contract with the firmware and
    configurator -- changing GPIO numbers here requires coordinated updates
    across three repos.
2026-08-16 Guard the keycap pitch against accidental mutations
    Add explicit assertion that KEY_PITCH == 19.05 (the mechanical standard)
    rather than relying only on delta comparisons against the pitch itself,
    which would pass even if the constant was changed. Existing delta assertions
    remain and continue to verify that key_xy() actually uses the pitch on both
    axes.
2026-08-16 Add the XIAO ESP32-C6 header footprint
    Two 1×7 through-hole female headers (2.54 mm pitch, 17.78 mm row spacing)
    to socket the Seeed XIAO ESP32-C6 microcontroller board. Footprint includes
    a corrected geometry test that verifies pad pitch and row spacing cannot
    drift without detection.
    [test_footprints.py]
2026-08-16 Fix silkscreen layer to clear pads per KiCad convention
    Move true body outline (17.5 × 21 mm) to F.Fab layer (overlap with pads
    harmless there); shift F.SilkS envelope outward to ±10.2 mm to clear pad
    extents (±9.74 mm) by 0.46 mm, eliminating silkscreen-over-copper DRC
    violations. All tests pass (5 tests, geometry verified).
2026-08-16 Add the EC11 rotary encoder footprint
    Standard vertical EC11 with 5 electrical pads (A/C/B encoder + 2 switch
    terminals) and 2 mounting posts. Silkscreen envelope (±7.7 mm) clears
    mounting post extents (4.0..7.2 mm) by 0.5 mm; true body outline on
    F.Fab layer. All tests pass (5 tests collected).
    Claude-Session: https://claude.ai/code
2026-08-16 Generate the schematic: matrix, encoder, LED chain, power
    build_nets() maps the 3x3 matrix (COL->SW->D->ROW, encoder push switch at
    R0C2 in place of SW02), the 9-LED serial chain off a level shifter fed from
    GPIO20, and power (VSYS from the JST battery input; LEDs on VSYS, not
    +3V3, since SK6812MINI-E specs a 3.7V VDD minimum). build_sch() translates
    logical pad names to real footprint pad numbers via PAD_MAP and emits the
    schematic using generate_macropad.py's exposed s-expression primitives
    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
    [smk_test_board.kicad_sch]
2026-08-16 Fix diode polarity, drop +3V3, wire U2 as the real level shifter
    Controller review round 1 on Task 5, all three self-review concerns
    confirmed real:
    - PAD_MAP had D_SOD-123_Back's A/K pads backwards (settled from the
    sibling's fp_diode(ref, x, y, rot, n_k, n_a, ...), which takes the
    cathode net first -- pad 1 = K, pad 2 = A). Fixed the map and flipped
    the diode's schematic instance placement to rot=180 so it still reads
    correctly on the sheet (net topology was never wrong, since labels
    attach by pin number; only the pin-to-side mapping needed to flip).
    - Removed the +3V3 net outright instead of padding it to two members --
    nothing on this board actually consumes regulated 3.3V n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
    [smk_test_board.kicad_sch]
2026-08-16 Place the board: key field, per-key LEDs, XIAO, encoder
    build_pcb() places all 35 footprints: the 3x3 key field (8x
    SW_Gateron_KS33_HS + 9x SK6812MINI_E LED + 9x D_SOD-123_Back diode, per
    gm.fp_gateron/fp_diode called directly -- both already produce this
    board's exact footprint geometry, byte-identical to the copied .pretty
    files), the EC11 at row0/col2 (replacing that position's switch, sharing
    its cell with D02 and RGB3), XIAO_ESP32C6_HEADERS below the key field,
    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
    [smk_test_board.kicad_pcb]
2026-08-16 Fix round 1: move LEDs off the switch boss, wire missing decoupling
    Controller review round 1 on Task 6, both concerns confirmed real:
    - LED moved from key centre to (kx, ky+5.9) -- 5.9mm south, the offset
    generate_kbd_rp2040.py:163 documents as the standard south-facing SMD
    LED position for MX-compatible/low-profile switches. Centre landed
    square on the switch's own Ø5.2mm boss NPTH, which is exactly what the
    round-1 kicad-cli DRC caught. test_leds_sit_under_their_keys replaced
    with test_leds_sit_at_the_south_facing_led_window (controller-supplied).
    Re-running DRC confirms the boss violations are gone, but a DIFFERENT
    hole_clearance violation appears in their place: at 5.9m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
    [smk_test_board.kicad_pcb]
2026-08-16 Fix round 2: LEDs to the real north window, obstacle-driven cap search
    Controller review round 2 on Task 6, both concerns confirmed real and
    fixed at the root rather than by hand.
    - LED offset corrected from 5.9mm south to -6.025mm north
    (kx, ky-6.025). Round 1 quoted generate_kbd_rp2040.py:163-170's prose
    changelog entry ("5.9mm south... confirmed clear of the switch's own
    SMD pads"), which turned out to describe an earlier, since-superseded
    attempt -- the code that file actually ships (:2050-2059,
    LED_OFFSET_Y = -6.025) moved north after finding south left the LED's
    own pads on the same side as the switch's leg NPTH holes, "no matter
    how it was routed". test_leds_sit_at_the_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
    [smk_test_board.kicad_pcb]
2026-08-16 Add the test board's reference keymap
    Claude-Session: https://claude.ai/code/session_01RrNSSSsf75egXawfTDj93k
2026-08-16 Add DRC-clean fabrication output and ordering notes
    DRC is at 16 errors (courtyards_overlap, unconnected_items) and 135 total
    with warnings -- all triaged in docs/fabrication.md as non-blocking:
    same-key courtyard overlaps and ratsnest-only unconnected items are
    expected by design, lib_footprint_issues is a DRC-run environment
    artifact, and remaining silk crowding is inherent to the deliberately
    tight 19.05mm key pitch.
    Moved the board's title silk text off mounting hole H1's silk circle and
    the top board edge -- a free fix that cleared silk_edge_clearance (1->0)
    and trimmed silk_over_copper/silk_overlap by 2 each, confirmed via a full
    regenerate + pytest + DRC re-run.
    export_fab.py drives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
    [smk_test_board.kicad_pcb]
2026-08-16 Fix round 1: encoder position in the reference keymap, MAX_BONDS wording
    Ruling 1: the mo:1 layer key belongs on the encoder's push-switch
    (matrix row0/col2 -- confirmed by generate_test_board.py's build_nets()
    and the design spec), not on the ordinary switch at row2/col2 where
    Task 9 placed it. Fixed keymap.json and updated bring-up.md's Step 5 to
    match: holding the encoder now naturally switches layers, per the
    design intent.
    Ruling 2: CONFIG_BT_NIMBLE_MAX_BONDS=4 lives on the unmerged
    ble-custom-gatt branch, not on test-board-config (=1 here). Rewrote
    Step 3b from a menuconfig instruction (which would only land in the
    gitignored, machine-local sdkconfig and silently revert) into a
    prereq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
2026-08-16 Fix round 2: serpentine LED chain order, tg: dead-end in bring-up
    Finding 1 (hardware defect): the LED chain was wired raster
    (i = r*COLS+c+1), but firmware's ledChainIndex() (SMKCore/
    LEDChainMapping.swift), which RGBLighting.swift actually indexes at
    runtime, is serpentine -- even rows col0->COLS-1, odd rows reversed.
    On this 3x3 board only row 1 disagrees between the two formulas (rows
    0/2 coincide), which is why it passed review for several rounds.
    Fixed generate_test_board.py's chain-index formula to match
    ledChainIndex exactly, regenerated the schematic/PCB (only RGB4/C4 and
    RGB6/C6 trade places; nothing else moves), and added a dedicated test
    that checks all 9 positions against the tr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
    [smk_test_board.kicad_pcb]
2026-08-16 Mill the SK6812MINI-E light windows into all nine LEDs
    _fp_sk6812mini_tb() re-rendered the SK6812MINI-E footprint inline and
    emitted 4 pads, 5 B.SilkS lines, a B.CrtYd rect, 2 B.Fab items and the
    3D model -- then stopped. The library master
    smk_test_board.pretty/SK6812MINI_E.kicad_mod additionally carries 20
    Edge.Cuts primitives (8 fp_line + 12 fp_arc) forming the ~3.4 x 3.0mm
    rounded-rect cutout, plus the pin-1 silk polarity triangle. None of that
    was emitted.
    These are REVERSE-MOUNT LEDs on the back of the board, shining forward
    through it into each switch's north window. With no milled openings they
    do nothing at all, and it cannot be reworked after fabrication.
    grep -c Edge.Cuts smk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
    [smk_test_board.kicad_pcb]
2026-08-16 Wire the battery to the XIAO, add the VBAT divider, complete the schematic
    Three defects with one shape: parts that build_nets()/build_pcb() should
    have carried and didn't, or carried and never told the schematic about.
    1. The battery never reached the XIAO.
    J1 (the JST cell connector) fed VSYS, and VSYS fed the nine SK6812 VDD
    pins, C1-C9, C_BULK and U2's VCC -- but nothing tied VSYS to U1. The
    board could not run untethered, the XIAO's onboard charger was never in
    circuit with the cell, and on USB with no cell fitted the whole LED
    chain and the level shifter were unpowered.
    The XIAO's BAT+/BAT- are solder pads on the module's UNDERSIDE and it
    seats on female headers,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
    [smk_test_board.kicad_pcb, smk_test_board.kicad_sch]
2026-08-16 Register both footprint libraries, emit the .kicad_pro, make regeneration reproducible
    Three things the project promised or implied and didn't do.
    1. No .kicad_pro and no fp-lib-table were ever written, although the
    design spec's Sec.5 promises smk_test_board.kicad_{pro,sch,pcb}.
    docs/fabrication.md blamed the resulting 46 lib_footprint_issues DRC
    warnings on "running kicad-cli outside the full KiCad project
    environment". That explanation was plausible and wrong: kicad-cli reads
    the project directory perfectly well; there was simply nothing
    registered for either smk_test_board: or kbd: to resolve against.
    generate_test_board.py now writes smk_test_board/fp-lib-table an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
    [smk_test_board.kicad_pcb]
2026-08-16 Correct the docs against the board, and the spec's VBAT premise
    docs/fabrication.md
    - Test count: said "12/12 tests pass" at :133 and :182. It was 13 by the
    time that was last edited and is 23 now. The :182 instance is in the
    ordering checklist -- the one number an operator is told to match.
    - DRC section rewritten as a was/now table with every moved count
    explained: courtyards_overlap 16 -> 16, unconnected_items 86 -> 94 (+8,
    itemised per net), lib_footprint_issues 46 -> 0, lib_footprint_mismatch
    0 -> 9 (new check, newly able to run), silk_over_copper 37 -> 38,
    silk_overlap 36 -> 38, silk_edge_clearance 0 -> 1, copper_edge_clearance
    0 -> 0 (via 38, including one real defect).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
    [export_fab.py]
2026-08-16 Fix battery connector BOM/schematic naming: JST-PH -> JST-SH
    The board's footprint (JST_SH_SM02B_2pin_Back) has always been JST SH,
    1.0mm pitch, but the BOM, spec, bring-up doc, and the schematic's own
    symbol/instance value strings all said "JST-PH" (2.0mm pitch) -- a
    different, incompatible connector. Someone following the BOM would order
    a PH connector and a cell with a PH pigtail, and neither would fit.
    Corrects every JST-PH mention to JST SH (SM02B-SRSS-TB or equivalent),
    and adds a prominent BOM-area note in fabrication.md: single-cell Li-ion
    pouch cells commonly ship with a JST-PH 2.0mm pigtail that will not mate
    with this board's SH connector, so the buyer needs an SH-pigtail cell, a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
    [smk_test_board.kicad_sch]
2026-08-16 Correct the copper-to-slot clearance claim and its checklist commands
    docs/fabrication.md claimed KiCad measures to the outer edge of the 0.12mm
    Edge.Cuts stroke and that the gap to the "nominal cut path" is 0.3067mm --
    "the number to compare against a fab's published copper-to-slot
    capability." That's false, disproved directly: widening every Edge.Cuts
    stroke on the LED window from 0.12/0.15mm to 0.4mm left every reported DRC
    clearance unchanged. KiCad ignores Edge.Cuts stroke width; 0.2467mm, as it
    reports, is already the copper-to-centreline number. Reconstructing the
    corner arcs exactly (r=0.5mm, centres at footprint-local +-(1.3171,
    1.1171)mm) puts the true minimum at ~0.2329mm.
    Change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
2026-08-16 Report the true SK6812 light-window opening, not just arc control points
    test_footprints.py asserted 3.488 x 3.088mm and fabrication.md said
    "~3.4 x 3.0mm" for the milled LED light window; both measure only the
    bounding box of the corner arcs' CONTROL POINTS. The arcs bulge ~0.073mm
    past their own endpoints, so the real milled opening is 3.634 x 3.234mm --
    about 0.15mm bigger per axis than documented, which is the kind of gap
    that breaks a keycap or light-pipe design built against the stated number.
    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
2026-08-16 Note RGB3's expected dimness in the bring-up LED step, not just fabrication.md
    docs/fabrication.md's DRC triage already records that the EC11's body
    covers ~49% of RGB3's light window (row 0 / col 2), an accepted design
    trade-off. But that document isn't where an operator is looking during
    Step 9's LED bring-up -- they're watching the LEDs and may log the dimness
    as a fault. Adds the same note directly to Step 9, right before the
    per-key checklist, so it's read at the point of observation.
    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
2026-08-16 Widen the back-side polarity guard to every back-side footprint, not just AUX_PARTS
    test_back_side_passives_are_all_nonpolar only iterated tb.AUX_PARTS and
    additionally required fpname == "RC_0603", so a polarised back-side part
    placed outside AUX_PARTS -- or through the same mismatched-mirror helper
    under a different footprint name -- would slip past silently. The intent
    (catching a polarised or pin-asymmetric part run through gm's generic
    side="B" mirror helper, whose X-axis-vs-Y-axis convention differs from
    KiCad's own flip) deserves the broader check.
    Now parses ref/footprint/value straight out of build_pcb()'s own text for
    every footprint the board actually places, so nothing new place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
    [test_test_board.py]
2026-08-16 Add a README
    Covers what the board is for, the four-way pin contract, the serpentine
    LED chain, how to regenerate and test, and the things that are known and
    accepted rather than defects (ratsnest-only, the relaxed copper-to-edge
    rule and its precedent, RGB3's partly-covered window, the JST SH vs PH
    pitch trap).
    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
2026-10-30 Route the board: router.py generates the copper; shrink to 65.7 x 91.73 mm
    router.py rasterises every obstacle onto a 0.2 mm grid and routes with an
    8-direction A* (turn and via costs), shortest MST edge first; GND is a pour
    on both layers with a stub via per pad. The outline is now derived from the
    placement. DRC with --refill-zones: 16 errors / 0 unconnected, as unrouted.
    28 tests pass.
    Claude-Session: https://claude.ai/code/session_01PWVS4DMn5rniJecYgbPE6J
